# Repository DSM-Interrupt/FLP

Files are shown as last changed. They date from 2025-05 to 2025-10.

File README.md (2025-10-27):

# 구성

project FLP의 기기의 회로도, PCB, FW 코드 등이 담긴 파일입니다.
호스트 기기의 프레임 워크는 ESP-IDF를 이용하였고 Espressif ide를 이용하여서 CMAKE 형식의 프로젝트로 제작되었습니다.
터미널 기기의 프레임 워크는 STMCUBE를 이용하였습니다. 
host 기기의 같은경우 MCU는 ESP32-WROOM-32E를 이용하였으며 terminal기기의 경우 STM32F103C8T6을 사용하였습니다.

## 세부내용
### Hardware
- 433MHz 대역 통신을 위해 SX1278 모듈 기반의 안테나 매칭을 포함한 LoRa RF 공통 회로 설계
- MCP73831(Li-Po 충전) 및 AP2112K-3.3(LDO)을 사용하여 USB-C/배터리 입력을 받는 3.3V 전원 시스템 공통 회로 구성
- CP2104 USB-to-UART 브릿지 IC와 USB-C 커넥터를 사용한 PC 시리얼 통신 및 펌웨어 다운로드 공통 회로 구현
- L86-M33 GPS 모듈을 탑재하여 위치 정보 수집을 위한 공통 회로 및 안테나 인터페이스 설계
- Host(ESP32) 보드에 펌웨어의 효율적인 디버깅을 위한 JTAG 인터페이스 회로 추가 설계

### Firmware
- Host(ESP32) 펌웨어는 C 언어와 ESP-IDF(FreeRTOS)를 기반으로, Terminal(STM32F103) 펌웨어는 C 언어와 HAL 라이브러리를 기반으로 개발하여 LoRa 통신 시스템을 구축
- Terminal은 UART2로 GPS 모듈의 NMEA 센텐스를 파싱하며, 5초 주기 또는 '호출'/'위험' 버튼 입력 시 고유 ID, GPS 좌표, Target ID, 위험 상태를 "ID,Lat,Lon,TargetID,Danger" 형식의 문자열 패킷으로 LoRa 전송
- Host는 SPI를 통해 이 LoRa 패킷을 수신, split_lora_response 함수로 파싱하여 Target ID를 확인하고, TerminalDevice 구조체 배열로 관리되는 단말기 목록의 최신 GPS 좌표와 위험 상태를 갱신
- Host는 Wi-Fi(AP+STA 모드)로 인터넷에 연결하며, WSS 클라이언트를 통해 원격 서버로 모든 단말기 정보와 자체 GPS 수신 정보를 통합하여 주기적으로 JSON 전송
- Wi-Fi AP 모드에서 Captive Portal 기능을 포함한 웹 서버를 구동하여 사용자에게 Wi-Fi 연결 정보 및 AP 정보 설정 페이지를 제공하며, 이 설정값들과 등록된 단말기 ID 목록은 NVS에 영속 저장
- 특정 GPIO 버튼(CTRL + FIND_HOST) 조합을 통해 10초간 '단말기 등록 모드'로 진입하며, 이 동안 수신된 "REG,<ID>,<TARGET_ID>" 형식의 LoRa 등록 요청 패킷을 처리하여 새로운 단말기를 시스템에 추가하고 NVS에 저장

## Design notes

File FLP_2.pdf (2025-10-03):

# FLP

## Find Lost People

## 열악한 상황 속에도 사용할 수 있는 범용 위치 관리 솔루션

## 프로젝트 차별점

가. 단가: 전용 기기로 설계되어 대량 생산이 용이하며, 부품 배치 최적화, 부품 수 축소 및 소자 용량 조정을

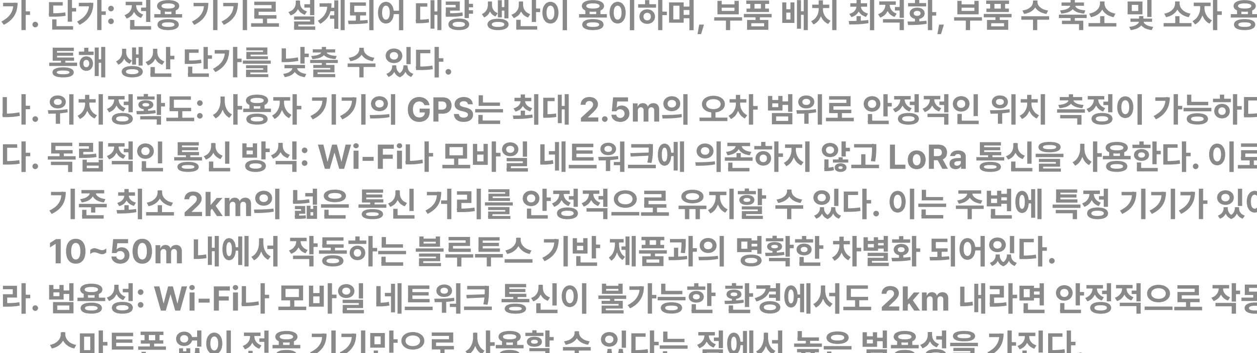
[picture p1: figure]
통해 생산 단가를 낮출 수 있다.

나. 위치정확도: 사용자 기기의 GPS는 최대 2.5m의 오차 범위로 안정적인 위치 측정이 가능하다.
다. 독립적인 통신 방식: Wi-Fi나 모바일 네트워크에 의존하지 않고 LoRa 통신을 사용한다. 이로써 도심 기준 최소 2km의 넓은 통신 거리를 안정적으로 유지할 수 있다. 이는 주변에 특정 기기가 있어야만 10~50m 내에서 작동하는 블루투스 기반 제품과의 명확한 차별화 되어있다.
라. 범용성: Wi-Fi나 모바일 네트워크 통신이 불가능한 환경에서도 2km 내라면 안정적으로 작동하며, 스마트폰 없이 전용 기기만으로 사용할 수 있다는 점에서 높은 범용성을 가진다.

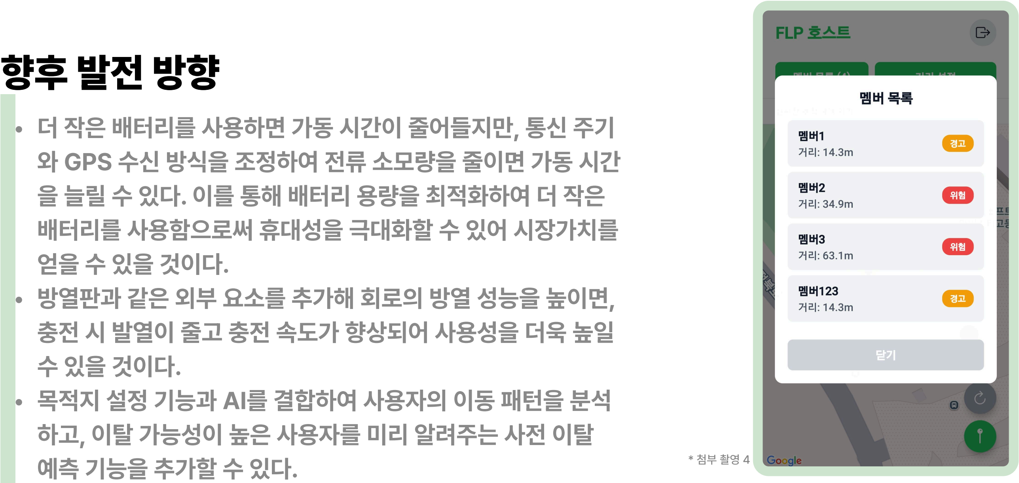
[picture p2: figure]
더 작은 배터리를 사용하면 가동 시간이 줄어들지만, 통신 주기 와 GPS 수신 방식을 조정하여 전류 소모량을 줄이면 가동 시간 을 늘릴 수 있다. 이를 통해 배터리 용량을 최적화하여 더 작은 배터리를 사용함으로써 휴대성을 극대화할 수 있어 시장가치를 얻을 수 있을 것이다. 방열판과 같은 외부 요소를 추가해 회로의 방열 성능을 높이면, 충전 시 발열이 줄고 충전 속도가 향상되어 사용성을 더욱 높일 수 있을 것이다. 목적지 설정 기능과 AI를 결합하여 사용자의 이동 패턴을 분석 하고, 이탈 가능성이 높은 사용자를 미리 알려주는 사전 이탈; 예측 기능을 추가할 수 있다.
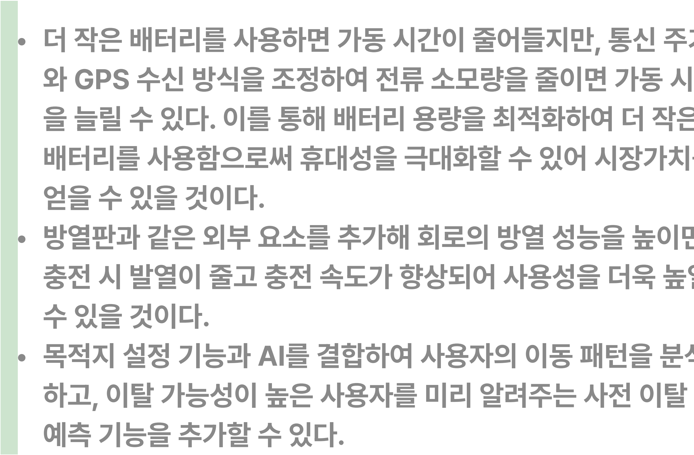
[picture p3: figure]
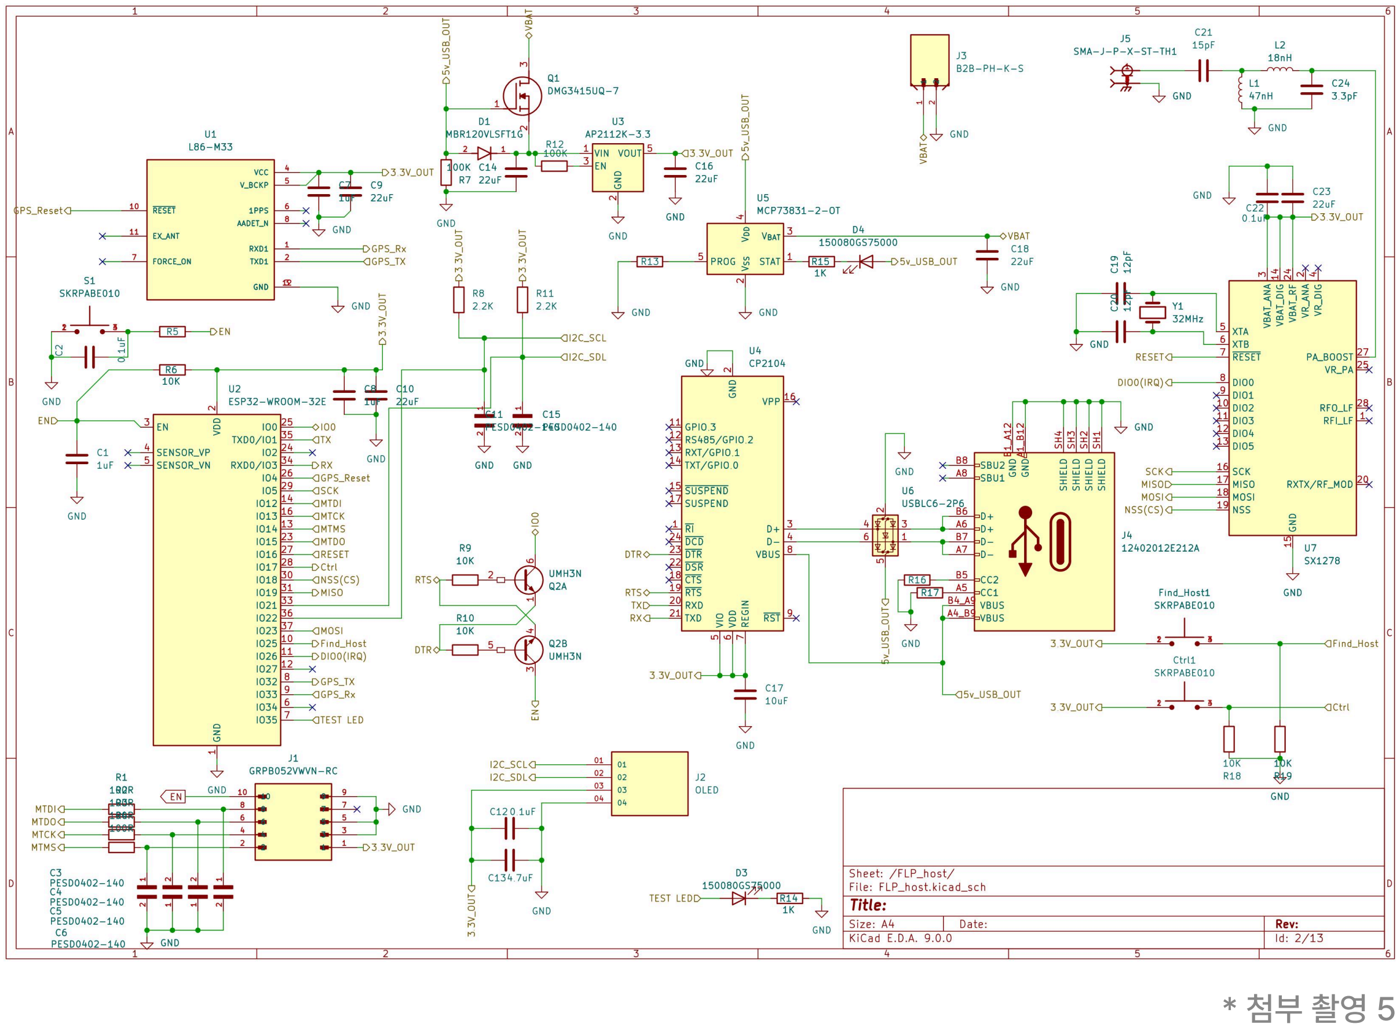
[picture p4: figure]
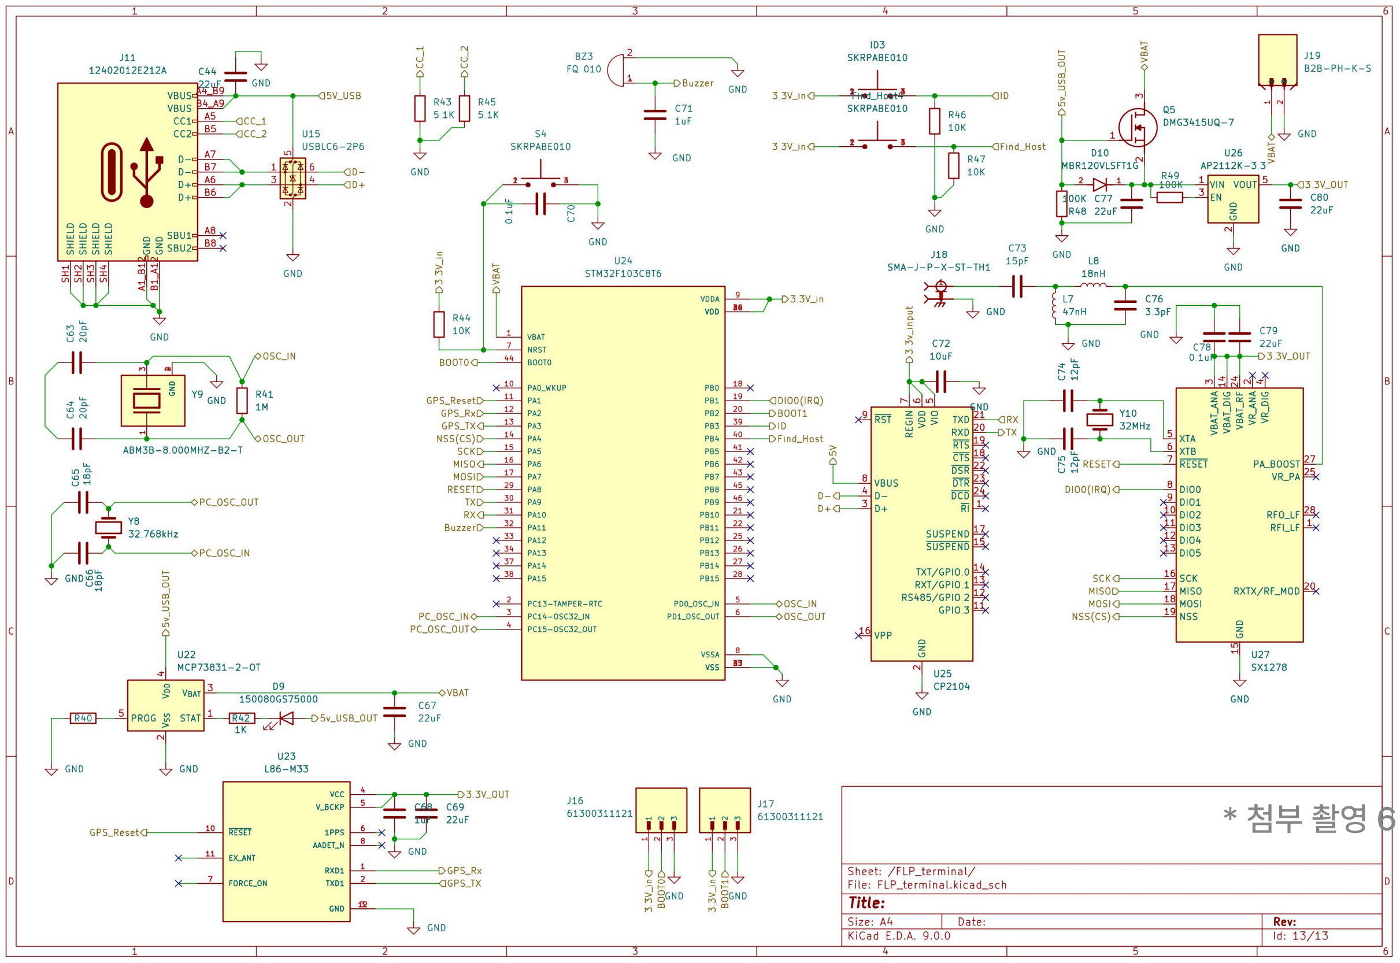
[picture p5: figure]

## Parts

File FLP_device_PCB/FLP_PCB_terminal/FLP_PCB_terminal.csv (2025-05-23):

Reference | Qty | Value | DNP | Exclude from BOM | Exclude from Board | Footprint | Datasheet
BT1 | 1 | Battery_Cell |  |  |  | Battery:BatteryHolder_MPD_BH-18650-PC2 | ~
BZ1 | 1 | Buzzer |  |  |  | Buzzer_Beeper:Buzzer_15x7.5RM7.6 | ~
C1,C2,C5,C10,C13,C16,C20,C29 | 8 | 22uF |  |  |  | Capacitor_SMD:C_0805_2012Metric | ~
C3,C11,C14,C15,C18,C23 | 6 | 4.7uF |  |  |  | Capacitor_SMD:C_0603_1608Metric | ~
C4,C8,C9,C19,C28 | 5 | 1uF |  |  |  | Capacitor_SMD:C_0603_1608Metric | ~
C6,C7 | 2 | 20pF |  |  |  | Capacitor_SMD:C_0402_1005Metric | ~
C12,C17,C24,C30,C31,C32 | 6 | 0.1uF |  |  |  | Capacitor_SMD:C_0603_1608Metric | ~
C21,C22 | 2 | PESD0402-140 |  |  |  | PESD0402-140:RESC1005X35N
C25,C26 | 2 | 12pF |  |  |  | Capacitor_SMD:C_0402_1005Metric | ~
C27 | 1 | 27pF |  |  |  | Capacitor_SMD:C_0603_1608Metric | ~
Charger1 | 1 | Charger |  |  |  | Connector_USB:USB_Micro-B_Amphenol_10103594-0001LF_Horizontal | ~
D1 | 1 | D_Schottky |  |  |  | Diode_SMD:DIOM5226X220N | ~
F1 | 1 | Polyfuse |  |  |  | Resistor_SMD:R_0603_1608Metric | ~
Find_Host1,ID1,S1,S2 | 4 | SKRPABE010 |  |  |  | Diode_SMD:SW_SKRPABE010
FL1 | 1 | BLM21PG221SN1D |  |  |  | BLM21PG221SN1D:BEADC2012X105N
J1 | 1 | SMA-J-P-X-ST-TH1 |  |  |  | SMA-J-P-X-ST-TH1:SAMTEC_SMA-J-P-X-ST-TH1
J2 | 1 | OLED |  |  |  | HTSW-104-20-TM-S:SAMTEC_HTSW-104-20-TM-S
L1 | 1 | 2.2uH |  |  |  | Inductor_SMD:L_1210_3225Metric | ~
L2 | 1 | WE-TPC_2811 |  |  |  | WE-TPC_2811:WE-TPC_2811
Q1 | 1 | Q_PMOS_DSG |  |  |  | SI2333DS-T1-E3:SOT95P237X112-3N | ~
R1,R2,R5,R6,R7,R14,R19,R20 | 8 | 10K |  |  |  | Resistor_SMD:R_0603_1608Metric | ~
R3 | 1 | 100R |  |  |  | Resistor_SMD:R_0402_1005Metric | ~
R4,R10 | 2 | 1K |  |  |  | Resistor_SMD:R_0603_1608Metric | ~
R8,R9 | 2 | 22R |  |  |  | Resistor_SMD:R_0402_1005Metric | ~
R11 | 1 | 1M |  |  |  | Resistor_SMD:R_0603_1608Metric | ~
R12 | 1 | 2M |  |  |  | Resistor_SMD:R_1210_3225Metric | ~
R13 | 1 | 180K |  |  |  | Resistor_SMD:R_1210_3225Metric | ~
R15,R18 | 2 | 2.2K |  |  |  | Resistor_SMD:R_0603_1608Metric | ~
R16,R17 | 2 | 5.1K |  |  |  | Resistor_SMD:R_0402_1005Metric | ~
U1 | 1 | AMS1117-3.3 |  |  |  | Package_TO_SOT_SMD:SOT-223-3_TabPin2 | http://www.advanced-monolithic.com/pdf/ds1117.pdf
U2 | 1 | STM32F103C8T6 |  |  |  | STM32F103C8T6:QFP50P900X900X160-48N
U3 | 1 | L86-M33 |  |  |  | L86-M33:XCVR_L86-M33
U4 | 1 | MCP73831-2-OT |  |  |  | Package_TO_SOT_SMD:SOT95P280X145-5N | http://ww1.microchip.com/downloads/en/DeviceDoc/20001984g.pdf
U5 | 1 | CP2104 |  |  |  | Package_DFN_QFN:QFN-24-1EP_4x4mm_P0.5mm_EP2.6x2.6mm | https://www.silabs.com/documents/public/data-sheets/cp2104.pdf
U6 | 1 | TPS61200DRC |  |  |  | Package_SON:Texas_S-PVSON-N10_ThermalVias | http://www.ti.com/lit/ds/symlink/tps61200.pdf
U7 | 1 | USBLC6-2P6 |  |  |  | Package_TO_SOT_SMD:SOT-666 | https://www.st.com/resource/en/datasheet/usblc6-2.pdf
U8 | 1 | SX1278 |  |  |  | Package_DFN_QFN:QFN-28-1EP_6x6mm_P0.65mm_EP4.8x4.8mm | https://semtech.my.salesforce.com/sfc/p/
UART1 | 1 | USB_C_Receptacle_USB2.0_16P |  |  |  | 12402012E212A:AMPHENOL_12402012E212A | https://www.usb.org/sites/default/files/documents/usb_type-c.zip
Y1 | 1 | ABM3B-8.000MHZ-B2-T |  |  |  | ABM3B-8.000MHZ-B2-T:XTAL_ABM3B-8.000MHZ-B2-T
Y2 | 1 | 32MHz |  |  |  | Crystal:Crystal_SMD_2012-2Pin_2.0x1.2mm | ~
Y3 | 1 | 32.768kHz |  |  |  | Crystal:Crystal_SMD_3215-2Pin_3.2x1.5mm | ~

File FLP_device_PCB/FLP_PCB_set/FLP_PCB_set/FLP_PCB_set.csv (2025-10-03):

Reference | Qty | Value | DNP | Exclude from BOM | Exclude from Board | Footprint | Datasheet
BZ1 | 1 | FQ 010 |  |  |  | Buzzer_Beeper:Buzzer_12x9.5RM7.6 | ~
C1,C7,C8,C28,C37 | 5 | 1uF |  |  |  | Capacitor_SMD:C_0603_1608Metric | ~
C2,C12,C22,C33,C36 | 5 | 0.1uF |  |  |  | Capacitor_SMD:C_0603_1608Metric | ~
C3,C4,C5,C6,C11,C15 | 6 | PESD0402-140 |  |  |  | PESD0402-140:RESC1005X35N
C9,C10,C14,C16,C18,C23,C25,C26,C27,C29,C34,C42 | 12 | 22uF |  |  |  | Capacitor_SMD:C_0805_2012Metric | ~
C13 | 1 | 4.7uF |  |  |  | Capacitor_SMD:C_0603_1608Metric | ~
C17 | 1 | 10uF |  |  |  | Capacitor_SMD:C_0805_2012Metric | ~
C19,C20,C30,C31 | 4 | 12pF |  |  |  | Capacitor_SMD:C_0402_1005Metric | ~
C21,C32 | 2 | 15pF |  |  |  | Capacitor_SMD:C_0402_1005Metric | ~
C24,C35 | 2 | 3.3pF |  |  |  | Capacitor_SMD:C_0402_1005Metric | ~
C38,C39 | 2 | 20pF |  |  |  | Capacitor_SMD:C_0402_1005Metric | ~
C40,C41 | 2 | 18pF |  |  |  | Capacitor_SMD:C_0603_1608Metric | ~
Ctrl1,Find_Host1,Find_Host2,ID1,S1,S2 | 6 | SKRPABE010 |  |  |  | Diode_SMD:SW_SKRPABE010
D1,D5 | 2 | MBR120VLSFT1G |  |  |  | MBR120VLSFT1G:DIOM3616X98N
D3,D4,D7 | 3 | 150080GS75000 |  |  |  | LED_SMD:LED_0805_2012Metric | ~
J1 | 1 | GRPB052VWVN-RC |  |  |  | Varistor:SULLINS_GRPB052VWVN-RC
J2 | 1 | OLED |  |  |  | HTSW-104-20-TM-S:SAMTEC_HTSW-104-20-TM-S
J3,J7 | 2 | B2B-PH-K-S |  |  |  | B2B_PH_K_S:JST_B2B-PH-K-S
J4,J6 | 2 | 12402012E212A |  |  |  | 12402012E212A:AMPHENOL_12402012E212A | https://www.usb.org/sites/default/files/documents/usb_type-c.zip
J5,J8 | 2 | SMA-J-P-X-ST-TH1 |  |  |  | SMA-J-P-X-ST-TH1:SAMTEC_SMA-J-P-X-ST-TH1
J9,J10 | 2 | 61300311121 |  |  |  | 61300311121:WURTH_61300311121
L1,L3 | 2 | 47nH |  |  |  | Inductor_SMD:L_0402_1005Metric | ~
L2 | 1 | 18nH |  |  |  | Capacitor_SMD:C_0402_1005Metric | ~
L4 | 1 | 18nH |  |  |  | Inductor_SMD:L_0402_1005Metric | ~
Q1,Q3 | 2 | DMG3415UQ-7 |  |  |  |  | https://www.diodes.com//assets/Datasheets/products_inactive_data/DMG3415UQ.pdf
Q2 | 1 | UMH3N |  |  |  | Package_TO_SOT_SMD:SOT-363_SC-70-6 | http://rohmfs.rohm.com/en/products/databook/datasheet/discrete/transistor/digital/emh3t2r-e.pdf
R1,R2,R3,R4 | 4 | 100R |  |  |  | Resistor_SMD:R_0603_1608Metric | ~
R5 | 1 | 22R |  |  |  | Resistor_SMD:R_0402_1005Metric | ~
R6,R9,R10,R18,R19,R26,R28,R29 | 8 | 10K |  |  |  | Resistor_SMD:R_0603_1608Metric | ~
R7,R12,R22,R23 | 4 | 100K |  |  |  | Resistor_SMD:R_0603_1608Metric | ~
R8,R11 | 2 | 2.2K |  |  |  | Resistor_SMD:R_0603_1608Metric | ~
R13,R24 | 2 | 2K |  |  |  | Resistor_SMD:R_0402_1005Metric | ~
R14,R15,R25 | 3 | 1K |  |  |  | Resistor_SMD:R_0603_1608Metric | ~
R16,R17 | 2 | 5.1K |  |  |  | Resistor_SMD:R_0402_1005Metric | ~
R20,R21 | 2 | 5.1K |  |  |  | Resistor_SMD:R_0603_1608Metric | ~
R27 | 1 | 1M |  |  |  | Resistor_SMD:R_0603_1608Metric | ~
U1,U12 | 2 | L86-M33 |  |  |  | L86-M33:XCVR_L86-M33
U2 | 1 | ESP32-WROOM-32E |  |  |  | RF_Module:ESP32-WROOM-32E | https://www.espressif.com/sites/default/files/documentation/esp32-wroom-32e_esp32-wroom-32ue_datasheet_en.pdf
U3,U10 | 2 | AP2112K-3.3 |  |  |  | Package_TO_SOT_SMD:SOT-23-5 | https://www.diodes.com/assets/Datasheets/AP2112.pdf
U4 | 1 | CP2104 |  |  |  | Package_DFN_QFN:QFN-24-1EP_4x4mm_P0.5mm_EP2.6x2.6mm | https://www.silabs.com/documents/public/data-sheets/cp2104.pdf
U5,U11 | 2 | MCP73831-2-OT |  |  |  | Package_TO_SOT_SMD:SOT-23-5 | http://ww1.microchip.com/downloads/en/DeviceDoc/20001984g.pdf
U6,U8 | 2 | USBLC6-2P6 |  |  |  | Package_TO_SOT_SMD:SOT-666 | https://www.st.com/resource/en/datasheet/usblc6-2.pdf
U7,U13 | 2 | SX1278 |  |  |  | Package_DFN_QFN:QFN-28-1EP_6x6mm_P0.65mm_EP4.8x4.8mm | https://semtech.my.salesforce.com/sfc/p/
U9 | 1 | STM32F103C8T6 |  |  |  | STM32F103C8T6:QFP50P900X900X160-48N
U14 | 1 | CH340N |  |  |  | Package_SO:SOP-8_3.9x4.9mm_P1.27mm | https://aitendo3.sakura.ne.jp/aitendo_data/product_img/ic/inteface/CH340N/ch340n.pdf
Y1,Y2 | 2 | 32MHz |  |  |  | Crystal:Crystal_SMD_2016-4Pin_2.0x1.6mm | ~
Y3 | 1 | ABM3B-8.000MHZ-B2-T |  |  |  | ABM3B-8.000MHZ-B2-T:XTAL_ABM3B-8.000MHZ-B2-T
Y4 | 1 | 32.768kHz |  |  |  | Crystal:Crystal_SMD_3215-2Pin_3.2x1.5mm | ~

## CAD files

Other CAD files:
case.blend
untitled.blend

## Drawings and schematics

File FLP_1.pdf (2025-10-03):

# FLP

## Find Lost People

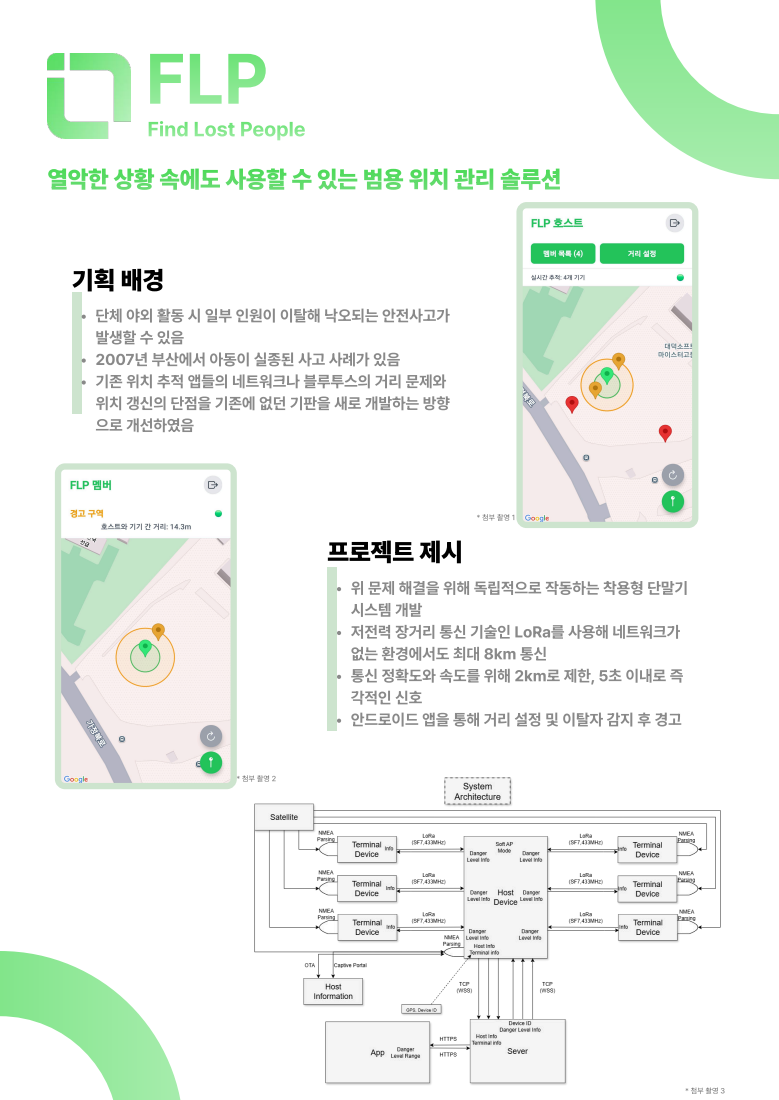
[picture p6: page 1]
프로젝트 제시

열악한 상황 속에도 사용할 수 있는 범용 위치 관리 솔루션

단체 야외 활동 시 일부 인원이 이탈해 낙오되는 안전사고가
발생할 수 있음
2007년 부산에서 아동이 실종된 사고 사례가 있음
기존 위치 추적 앱들의 네트워크나 블루투스의 거리 문제와
위치 갱신의 단점을 기존에 없던 기판을 새로 개발하는 방향
으로 개선하였음

위 문제 해결을 위해 독립적으로 작동하는 착용형 단말기
시스템 개발
저전력 장거리 통신 기술인 LoRa를 사용해 네트워크가
없는 환경에서도 최대 8km 통신
통신 정확도와 속도를 위해 2km로 제한, 5초 이내로 즉
각적인 신호
안드로이드 앱을 통해 거리 설정 및 이탈자 감지 후 경고

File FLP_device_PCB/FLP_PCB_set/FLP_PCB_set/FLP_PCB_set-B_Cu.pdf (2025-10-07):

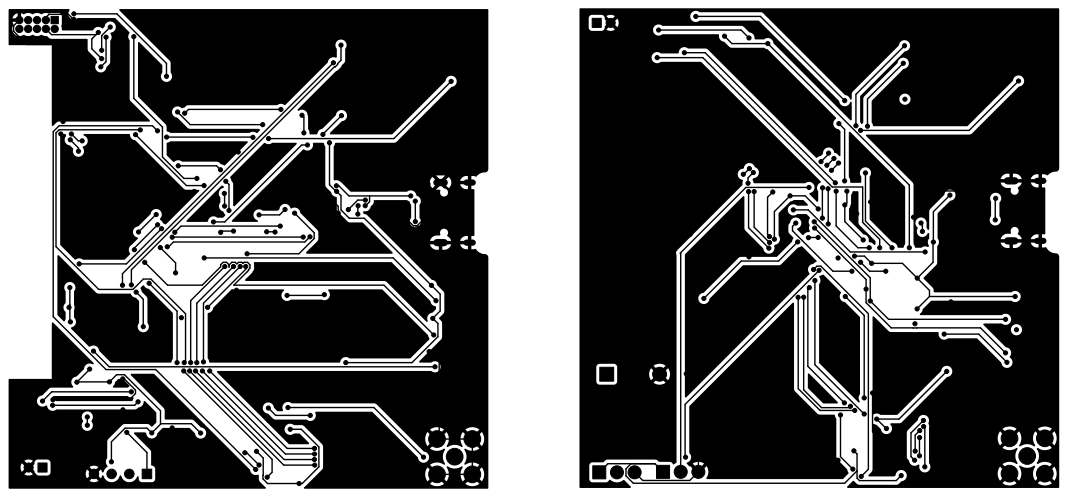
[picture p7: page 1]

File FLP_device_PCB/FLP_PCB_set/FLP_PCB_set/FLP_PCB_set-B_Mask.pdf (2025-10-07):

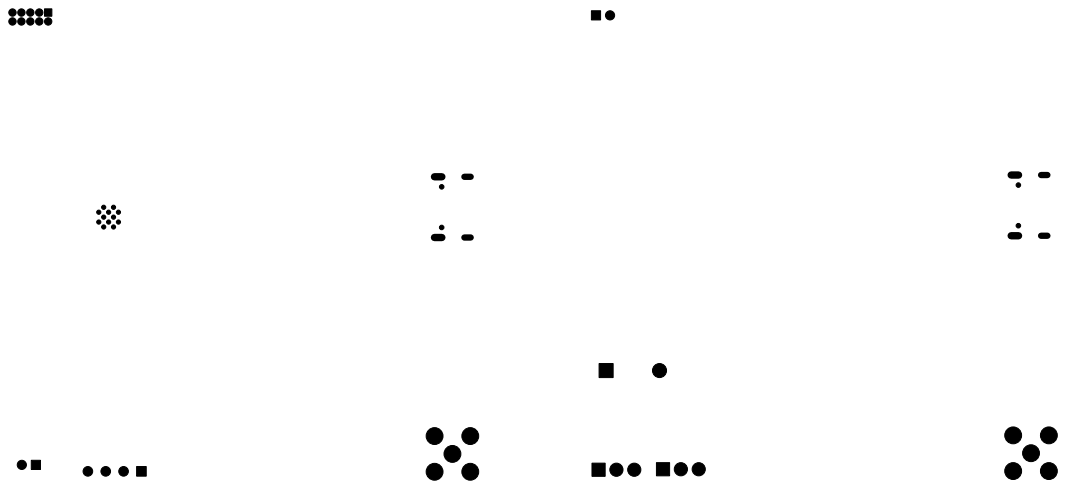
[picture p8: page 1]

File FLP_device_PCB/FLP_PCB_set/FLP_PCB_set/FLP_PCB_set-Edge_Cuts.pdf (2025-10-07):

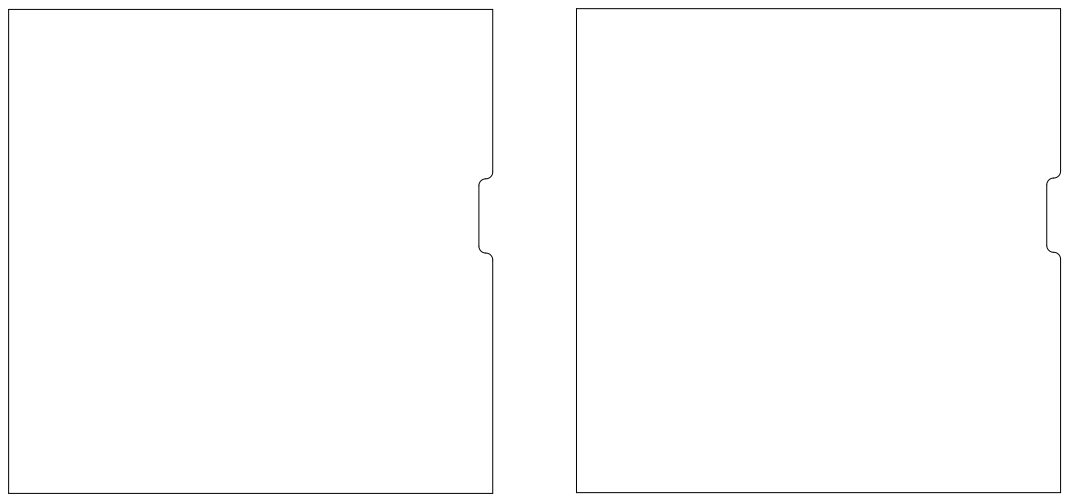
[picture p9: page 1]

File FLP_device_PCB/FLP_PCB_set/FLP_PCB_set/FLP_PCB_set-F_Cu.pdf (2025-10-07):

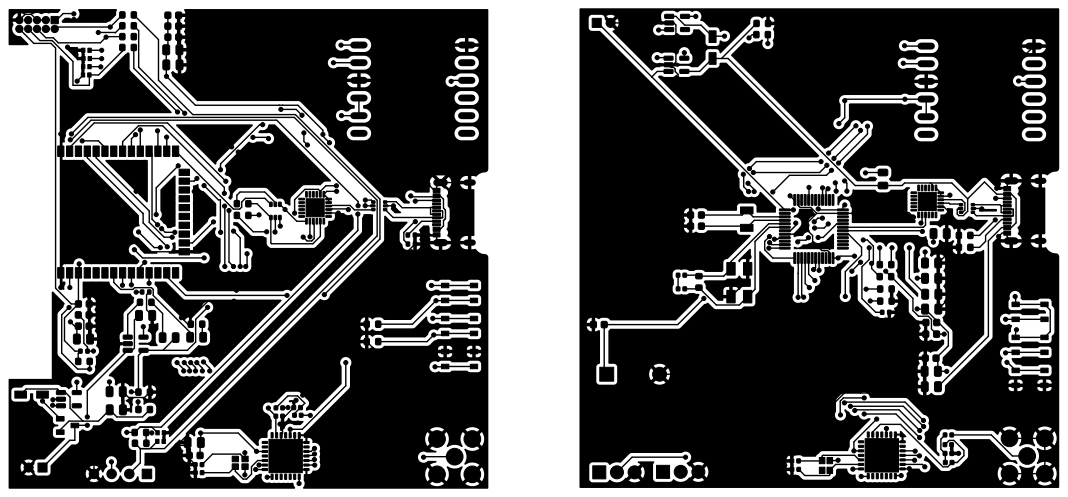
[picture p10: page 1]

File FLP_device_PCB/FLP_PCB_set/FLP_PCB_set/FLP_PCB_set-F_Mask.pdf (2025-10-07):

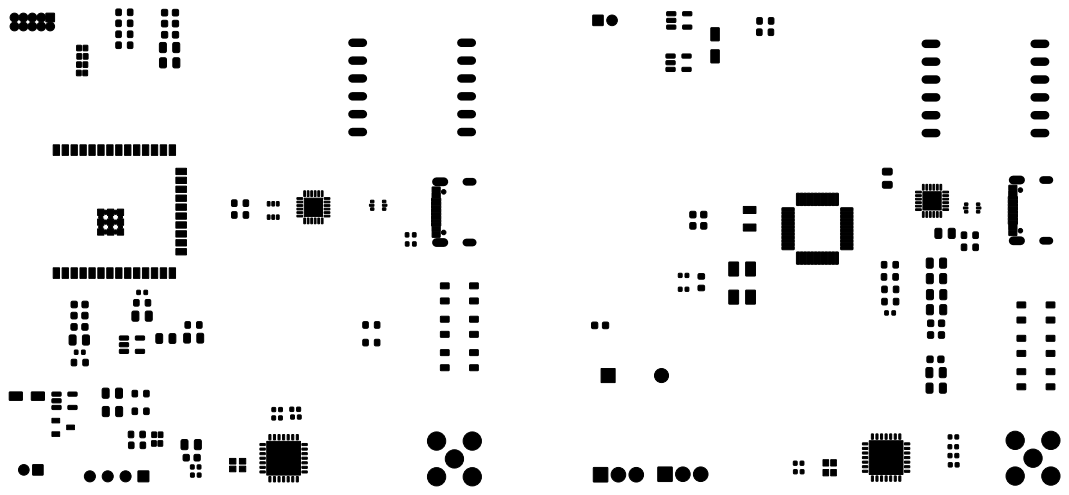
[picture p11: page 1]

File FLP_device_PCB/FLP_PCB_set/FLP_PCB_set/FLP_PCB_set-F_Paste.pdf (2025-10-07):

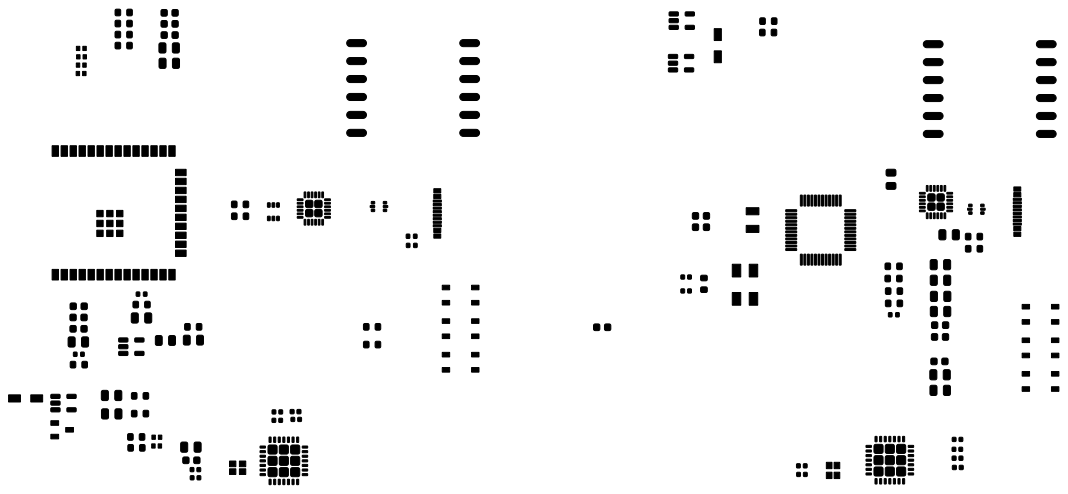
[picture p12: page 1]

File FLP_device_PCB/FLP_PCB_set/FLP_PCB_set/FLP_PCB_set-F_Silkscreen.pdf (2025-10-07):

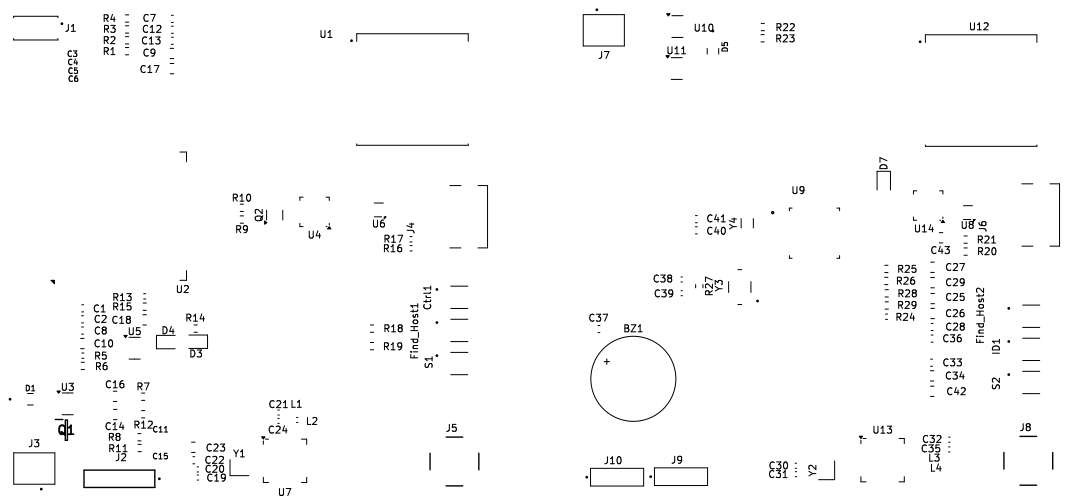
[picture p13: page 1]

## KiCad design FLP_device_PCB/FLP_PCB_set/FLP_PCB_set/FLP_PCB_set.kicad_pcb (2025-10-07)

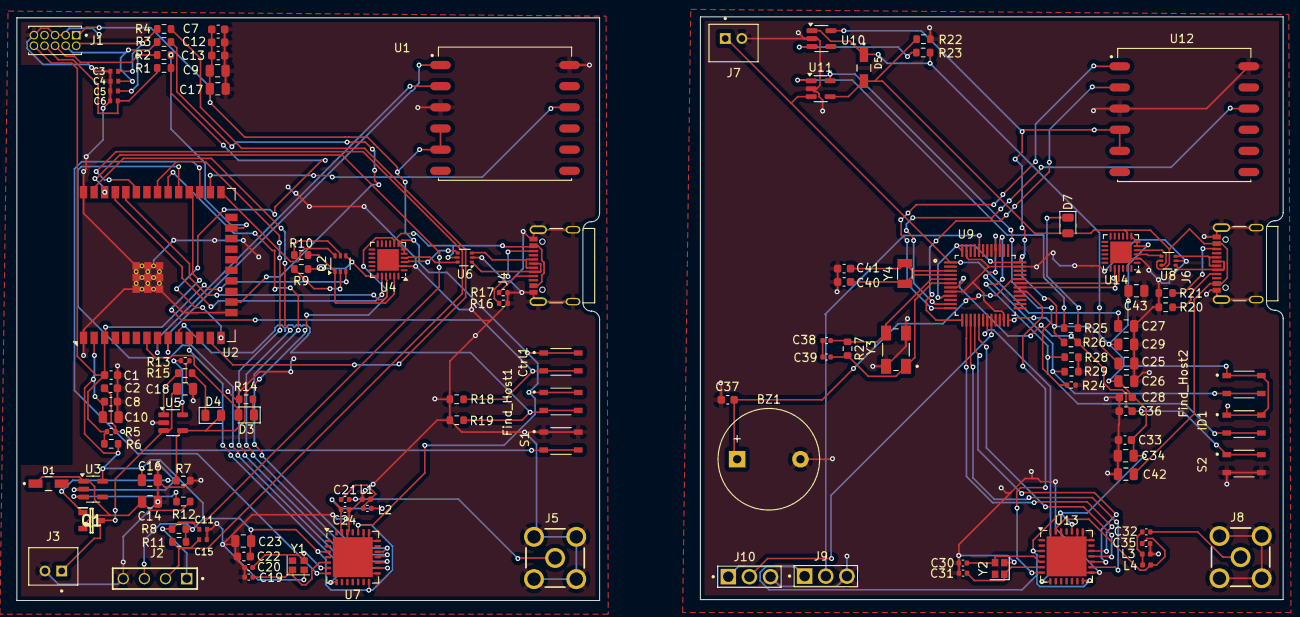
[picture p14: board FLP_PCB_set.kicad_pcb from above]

Board: 2 copper layers, 152.1 x 70.1 mm, 118 parts (0 on the bottom side), 93 nets.

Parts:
BZ1: FQ 010; Buzzer_12x9.5RM7.6
C1, C7, C8, C28, C37: 1uF; C_0603_1608Metric
C2, C12, C22, C33, C36: 0.1uF; C_0603_1608Metric
C3, C4, C5, C6, C11, C15: PESD0402-140; RESC1005X35N
C9, C10, C14, C16, C18, C23, C25, C26, C27, C29, C34, C42: 22uF; C_0805_2012Metric
C13: 4.7uF; C_0603_1608Metric
C17, C43: 10uF; C_0805_2012Metric
C19, C20, C30, C31: 12pF; C_0402_1005Metric
C21, C32: 15pF; C_0402_1005Metric
C24, C35: 3.3pF; C_0402_1005Metric
C38, C39: 20pF; C_0402_1005Metric
C40, C41: 18pF; C_0603_1608Metric
Ctrl1: SKRPABE010; SW_SKRPABE010
D1, D5: MBR120VLSFT1G; DIOM3616X98N
D3, D4, D7: 150080GS75000; LED_0805_2012Metric
Find_Host1, Find_Host2: SKRPABE010; SW_SKRPABE010
ID1: SKRPABE010; SW_SKRPABE010
J1: GRPB052VWVN-RC; SULLINS_GRPB052VWVN-RC
J2: OLED; SAMTEC_HTSW-104-20-TM-S
J3, J7: B2B-PH-K-S; JST_B2B-PH-K-S
J4, J6: 12402012E212A; AMPHENOL_12402012E212A
J5, J8: SMA-J-P-X-ST-TH1; SAMTEC_SMA-J-P-X-ST-TH1
J9, J10: 61300311121; WURTH_61300311121
L1, L3: 47nH; L_0402_1005Metric
L2: 18nH; C_0402_1005Metric
L4: 18nH; L_0402_1005Metric
Q1: DMG3415UQ-7; SOT96P240X110-3N
Q2: UMH3N; SOT-363_SC-70-6
R1, R2, R3, R4: 100R; R_0603_1608Metric
R5: 22R; R_0402_1005Metric
R6, R9, R10, R18, R19, R26, R28, R29: 10K; R_0603_1608Metric
R7, R12, R22, R23: 100K; R_0603_1608Metric
R8, R11: 2.2K; R_0603_1608Metric
R13, R24: 2K; R_0402_1005Metric
R14, R15, R25: 1K; R_0603_1608Metric
R16, R17: 5.1K; R_0402_1005Metric
R20, R21: 5.1K; R_0603_1608Metric
R27: 1M; R_0603_1608Metric
S1, S2: SKRPABE010; SW_SKRPABE010
U1, U12: L86-M33; XCVR_L86-M33
U2: ESP32-WROOM-32E
U3, U10: AP2112K-3.3; SOT-23-5
U4, U14: CP2104; QFN-24-1EP_4x4mm_P0.5mm_EP2.6x2.6mm
U5, U11: MCP73831-2-OT; SOT-23-5
U6, U8: USBLC6-2P6; SOT-666
U7, U13: SX1278; QFN-28-1EP_6x6mm_P0.65mm_EP4.8x4.8mm
U9: STM32F103C8T6; QFP50P900X900X160-48N
Y1, Y2: 32MHz; Crystal_SMD_2016-4Pin_2.0x1.6mm
Y3: ABM3B-8.000MHZ-B2-T; XTAL_ABM3B-8.000MHZ-B2-T
Y4: 32.768kHz; Crystal_SMD_3215-2Pin_3.2x1.5mm

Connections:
/FLP_host/3.3V_OUT: C7.1, C8.1, C9.1, C10.1, C12.1, C13.1, C16.1, C17.1, C22.1, C23.2, Ctrl1.1, Ctrl1.2, Find_Host1.1, Find_Host1.2, J1.1, J2.03, R6.2, R8.2, R11.2, U1.4 (VCC), U1.5 (V_BCKP), U2.2 (VDD), U3.5 (VOUT), U4.5 (VIO), U4.6 (VDD), U4.7 (REGIN), U7.3 (VBAT_ANA), U7.14 (VBAT_DIG), U7.24 (VBAT_RF)
/FLP_host/5v_USB_OUT: D1.2, D4.2 (A), J4.A4_B9 (VBUS), J4.B4_A9 (VBUS), Q1.1 (G), R7.1, U4.8 (VBUS), U5.4 (V_{DD}), U6.5 (VBUS)
/FLP_host/Ctrl: Ctrl1.3, Ctrl1.4, R18.1, U2.28 (IO17)
/FLP_host/DIO0(IRQ): U2.11 (IO26), U7.8 (DIO0)
/FLP_host/DTR: Q2.1 (E1), R10.1, U4.23 (~DTR)
/FLP_host/Find_Host: Find_Host1.3, Find_Host1.4, R19.1, U2.10 (IO25)
/FLP_host/GPS_Reset: U1.10 (~RESET), U2.26 (IO4)
/FLP_host/GPS_Rx: U1.1 (RXD1), U2.9 (IO33)
/FLP_host/GPS_TX: U1.2 (TXD1), U2.8 (IO32)
/FLP_host/I2C_SCL: C11.1, J2.01, R8.1, U2.36 (IO22)
/FLP_host/I2C_SDL: C15.1, J2.02, R11.1, U2.33 (IO21)
/FLP_host/IO0: Q2.6 (C1), U2.25 (IO0)
/FLP_host/MISO: U2.31 (IO19), U7.17 (MISO)
/FLP_host/MOSI: U2.37 (IO23), U7.18 (MOSI)
/FLP_host/MTCK: R3.1, U2.16 (IO13)
/FLP_host/MTDI: R1.1, U2.14 (IO12)
/FLP_host/MTDO: R2.1, U2.23 (IO15)
/FLP_host/MTMS: R4.1, U2.13 (IO14)
/FLP_host/NSS(CS): U2.30 (IO18), U7.19 (NSS)
/FLP_host/RESET: U2.27 (IO16), U7.7 (~RESET)
/FLP_host/RTS: Q2.4 (E2), R9.1, U4.19 (~RTS)
/FLP_host/RX: U2.34 (RXD0/IO3), U4.21 (TXD)
/FLP_host/SCK: U2.29 (IO5), U7.16 (SCK)
/FLP_host/TEST LED: D3.2 (A), U2.7 (IO35)
/FLP_host/TX: U2.35 (TXD0/IO1), U4.20 (RXD)
/FLP_host/VBAT: C18.1, J3.1, Q1.3 (D), U5.3 (V_{BAT})
/FLP_terminal/BOOT_Mode/3.3V_in: C26.1, C28.1, C29.1, C33.1, C34.2, C43.1, Find_Host2.1, Find_Host2.2, ID1.1, ID1.2, J9.1, J10.1, R26.1, U9.9 (VDDA), U9.24 (VDD), U9.36 (VDD), U9.48 (VDD), U10.5 (VOUT), U12.4 (VCC), U12.5 (V_BCKP), U13.3 (VBAT_ANA), U13.14 (VBAT_DIG), U13.24 (VBAT_RF), U14.5 (VIO), U14.6 (VDD), U14.7 (REGIN)
/FLP_terminal/BOOT_Mode/BOOT0: J9.2, U9.44 (BOOT0)
/FLP_terminal/BOOT_Mode/BOOT1: J10.2, U9.20 (PB2)
/FLP_terminal/Bat/5v_USB_OUT: C42.2, D5.2, D7.2 (A), J6.A4_B9 (VBUS), J6.B4_A9 (VBUS), R22.1, U8.5 (VBUS), U11.4 (V_{DD}), U14.8 (VBUS)
/FLP_terminal/Bat/VBAT: C27.1, J7.1, U9.1 (VBAT), U11.3 (V_{BAT})
/FLP_terminal/GPS/GPS_Reset: U9.11 (PA1), U12.10 (~RESET)
/FLP_terminal/GPS/GPS_Rx: U9.12 (PA2), U12.1 (RXD1)
/FLP_terminal/GPS/GPS_TX: U9.13 (PA3), U12.2 (TXD1)
/FLP_terminal/LoRa/DIO0(IRQ): U9.19 (PB1), U13.8 (DIO0)
/FLP_terminal/LoRa/MISO: U9.16 (PA6), U13.17 (MISO)
/FLP_terminal/LoRa/MOSI: U9.17 (PA7), U13.18 (MOSI)
/FLP_terminal/LoRa/NSS(CS): U9.14 (PA4), U13.19 (NSS)
/FLP_terminal/LoRa/RESET: U9.29 (PA8), U13.7 (~RESET)
/FLP_terminal/LoRa/SCK: U9.15 (PA5), U13.16 (SCK)
/FLP_terminal/STM32/Buzzer: BZ1.1 (+), C37.1, U9.32 (PA11)
/FLP_terminal/STM32/Find_Host: Find_Host2.3, Find_Host2.4, R29.1, U9.40 (PB4)
/FLP_terminal/STM32/ID: ID1.3, ID1.4, R28.1, U9.39 (PB3)
/FLP_terminal/STM32/OSC_IN: C38.2, R27.1, U9.5 (PD0_OSC_IN), Y3.3
/FLP_terminal/STM32/OSC_OUT: C39.2, R27.2, U9.6 (PD1_OSC_OUT), Y3.1
/FLP_terminal/STM32/PC_OSC_IN: C41.1, U9.3 (PC14-OSC32_IN), Y4.1
/FLP_terminal/STM32/PC_OSC_OUT: C40.1, U9.4 (PC15-OSC32_OUT), Y4.2
/FLP_terminal/STM32/RX: U9.31 (PA10), U14.21 (TXD)
/FLP_terminal/STM32/TX: U9.30 (PA9), U14.20 (RXD)
/FLP_terminal/UART_USB/CC_1: J6.A5 (CC1), R20.1
/FLP_terminal/UART_USB/CC_2: J6.B5 (CC2), R21.1
/FLP_terminal/UART_USB/D+: U8.4 (I/O2), U14.3 (D+)
/FLP_terminal/UART_USB/D-: U8.6 (I/O1), U14.4 (D-)
EN: C1.1, J1.10, Q2.3 (C2), R5.2, R6.1, U2.3 (EN)
GND: BZ1.2 (-), C1.2, C2.1, C3.2, C4.1, C5.1, C6.2, C7.2, C8.2, C9.2, C10.2, C11.2, C12.2, C13.2, C14.2, C15.2, C16.2, C17.2, C18.2, C19.1, C20.1, C22.2, C23.1, C24.2, C25.2, C26.2, C27.2, C28.2, C29.2, C30.1, C31.1, C33.2, C34.1, C35.2, C36.1, C37.2, C40.2, C41.2, C42.1, C43.2, J1.3, J1.5, J1.9, J2.04, J3.2, J4.A1_B12 (GND), J4.B1_A12 (GND), J4.SH1 (SHIELD), J4.SH2 (SHIELD), J4.SH3 (SHIELD), J4.SH4 (SHIELD), J5.2, J5.3, J5.4, J5.5, J6.A1_B12 (GND), J6.B1_A12 (GND), J6.SH1 (SHIELD), J6.SH2 (SHIELD), J6.SH3 (SHIELD), J6.SH4 (SHIELD), J7.2, J8.2, J8.3, J8.4, J8.5, J9.3, J10.3, L1.1, L3.1, R7.2, R13.1, R14.2, R16.1, R17.1, R18.2, R19.2, R20.2, R21.2, R22.2, R24.1, R28.2, R29.2, S1.1, S1.2, S2.3, S2.4, U1.3 (GND), U1.12 (GND), U2.1 (GND), U2.15 (GND), U2.38 (GND), U2.39 (GND), U3.2 (GND), U4.2 (GND), U4.25 (GND), U5.2 (V_{SS}), U6.2 (GND), U7.15 (GND), U7.21 (GND), U7.22 (GND), U7.23 (GND), U7.26 (GND), U7.29 (GND), U8.2 (GND), U9.8 (VSSA), U9.23 (VSS), U9.35 (VSS), U9.47 (VSS), U10.2 (GND), U11.2 (V_{SS}), U12.3 (GND), U12.12 (GND), U13.15 (GND), U13.21 (GND), U13.22 (GND), U13.23 (GND), U13.26 (GND), U13.29 (GND), U14.2 (GND), U14.25 (GND), Y3.2 (GND), Y3.4 (GND)
unnamed: C2.2, R5.1, S1.3, S1.4
unnamed: C3.1, J1.2, R4.2
unnamed: C4.2, J1.4, R3.2
unnamed: C5.2, J1.6, R2.2
unnamed: C6.1, J1.8, R1.2
unnamed: C21.1, L1.2, L2.1
unnamed: C21.2, J5.1
unnamed: C32.1, L3.2, L4.1
unnamed: C32.2, J8.1
unnamed: C38.1, C39.1
unnamed: D3.1 (K), R14.1
unnamed: D4.1 (K), R15.2
unnamed: D7.1 (K), R25.2
unnamed: J4.A5 (CC1), R17.2
unnamed: J4.B5 (CC2), R16.2
unnamed: J4.A6 (D+), J4.B6 (D+), U6.3 (I/O2)
unnamed: J4.A7 (D-), J4.B7 (D-), U6.1 (I/O1)
unnamed: J6.A6 (D+), J6.B6 (D+), U8.3 (I/O2)
unnamed: J6.A7 (D-), J6.B7 (D-), U8.1 (I/O1)
unnamed: C14.1, D1.1, Q1.2 (S), R12.2, U3.1 (VIN)
unnamed: Q2.2 (B1), R9.2
unnamed: Q2.5 (B2), R10.2
unnamed: C25.1, D5.1, R23.2, U10.1 (VIN)
unnamed: R12.1, U3.3 (EN)
unnamed: U4.3 (D+), U6.4 (I/O2)
unnamed: U4.4 (D-), U6.6 (I/O1)
unnamed: R13.2, U5.5 (PROG)
unnamed: R15.1, U5.1 (STAT)
unnamed: C24.1, L2.2, U7.27 (PA_BOOST)
unnamed: C19.2, U7.5 (XTA), Y1.2
unnamed: C20.2, U7.6 (XTB), Y1.1
unnamed: C36.2, R26.2, S2.1, S2.2, U9.7 (NRST)
unnamed: R23.1, U10.3 (EN)
unnamed: R24.2, U11.5 (PROG)
unnamed: R25.1, U11.1 (STAT)
unnamed: C35.1, L4.2, U13.27 (PA_BOOST)
unnamed: C30.2, U13.5 (XTA), Y2.2
unnamed: C31.2, U13.6 (XTB), Y2.1

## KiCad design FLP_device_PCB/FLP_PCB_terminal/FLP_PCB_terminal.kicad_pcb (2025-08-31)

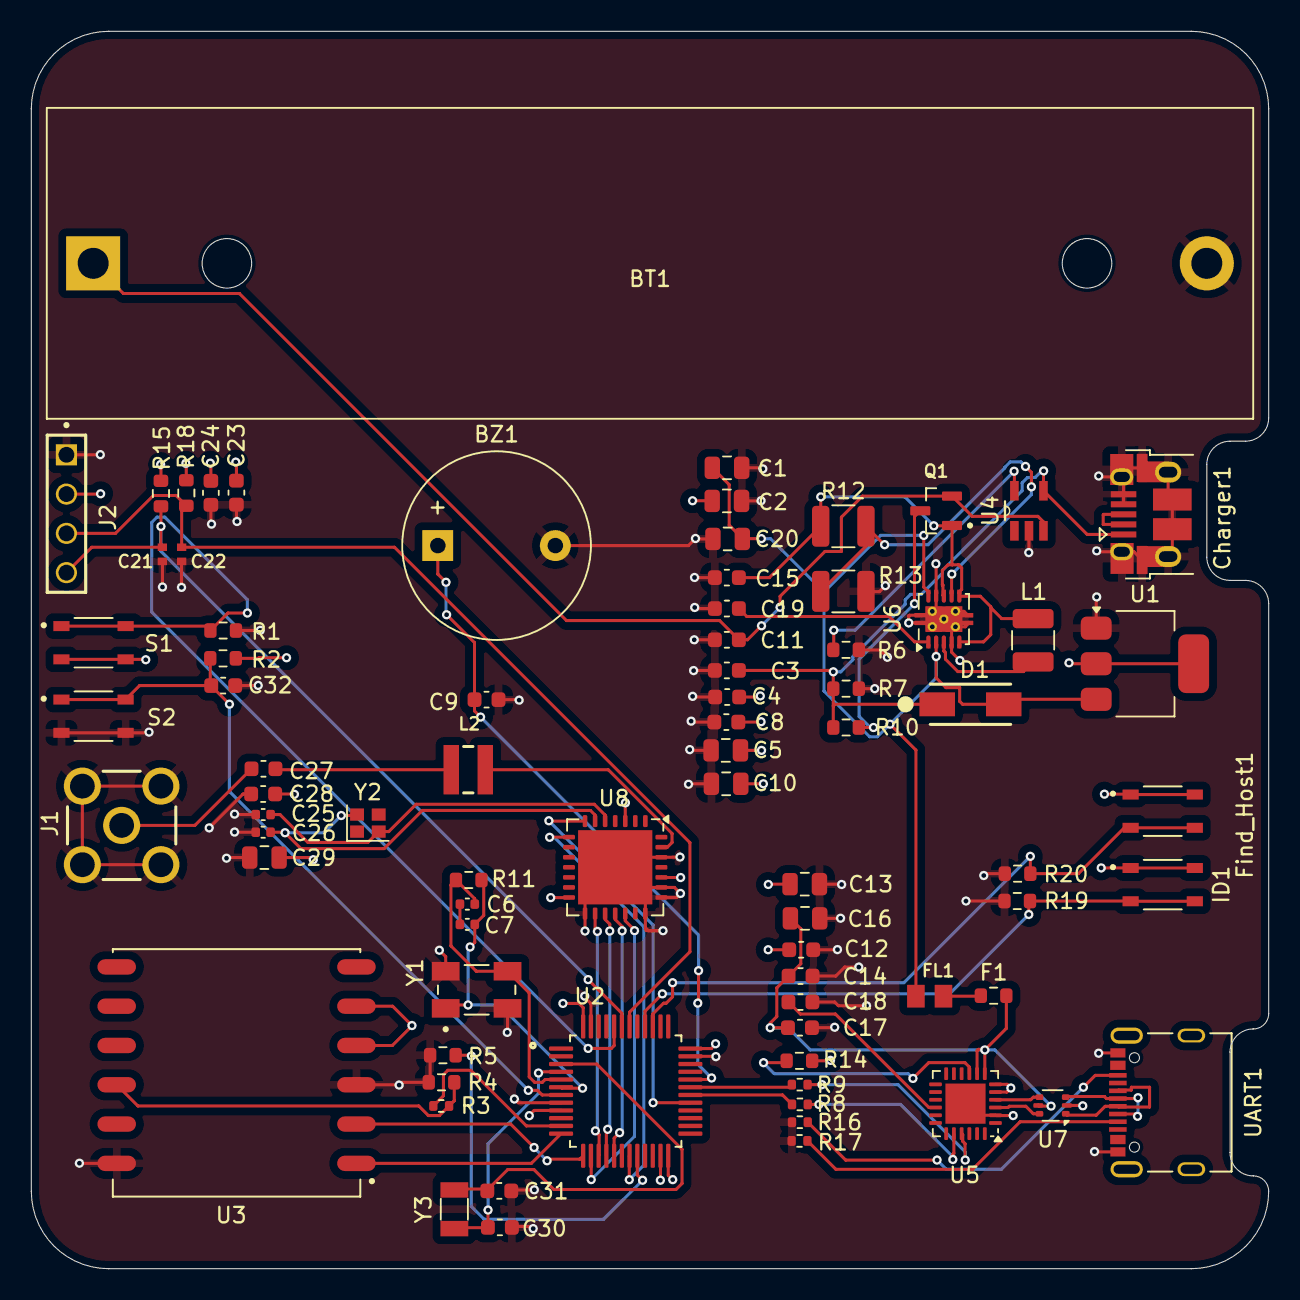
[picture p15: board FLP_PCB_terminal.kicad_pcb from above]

Board: 4 copper layers, 80.0 x 80.0 mm, 79 parts (0 on the bottom side), 54 nets.

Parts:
BT1: Battery_Cell; BatteryHolder_MPD_BH-18650-PC2
BZ1: Buzzer; Buzzer_12x9.5RM7.6
C1, C2, C5, C10, C13, C16, C20, C29: 22uF; C_0805_2012Metric
C3, C11, C14, C15, C18, C23: 4.7uF; C_0603_1608Metric
C4, C8, C9, C19, C28: 1uF; C_0603_1608Metric
C6, C7: 20pF; C_0402_1005Metric
C12, C17, C24, C30, C31, C32: 0.1uF; C_0603_1608Metric
C21, C22: PESD0402-140; RESC1005X35N
C25, C26: 12pF; C_0402_1005Metric
C27: 2.2pF; C_0603_1608Metric
Charger1: Charger; USB_Micro-B_Amphenol_10103594-0001LF_Horizontal
D1: D_Schottky; DIOM5226X220N
F1: Polyfuse; R_0603_1608Metric
FL1: BLM21PG221SN1D; BEADC2012X105N
Find_Host1: SKRPABE010; SW_SKRPABE010
ID1: SKRPABE010; SW_SKRPABE010
J1: SMA-J-P-X-ST-TH1; SAMTEC_SMA-J-P-X-ST-TH1
J2: OLED; SAMTEC_HTSW-104-20-TM-S
L1: 2.2uH; L_1210_3225Metric
L2: WE-TPC_2811
Q1: Q_PMOS_DSG; SOT95P237X112-3N
R1, R2, R5, R6, R7, R14, R19, R20: 10K; R_0603_1608Metric
R3: 100R; R_0402_1005Metric
R4, R10: 1K; R_0603_1608Metric
R8, R9: 22R; R_0402_1005Metric
R11: 1M; R_0603_1608Metric
R12: 2M; R_1210_3225Metric
R13: 180K; R_1210_3225Metric
R15, R18: 2.2K; R_0603_1608Metric
R16, R17: 5.1K; R_0402_1005Metric
S1, S2: SKRPABE010; SW_SKRPABE010
U1: AMS1117-3.3; SOT-223-3_TabPin2
U2: STM32F103C8T6; QFP50P900X900X160-48N
U3: L86-M33; XCVR_L86-M33
U4: MCP73831-2-OT; SOT95P280X145-5N
U5: CP2104; QFN-24-1EP_4x4mm_P0.5mm_EP2.6x2.6mm
U6: TPS61200DRC; Texas_S-PVSON-N10_ThermalVias
U7: USBLC6-2P6; SOT-666
U8: SX1278; QFN-28-1EP_6x6mm_P0.65mm_EP4.8x4.8mm
UART1: USB_C_Receptacle_USB2.0_16P; AMPHENOL_12402012E212A
Y1: ABM3B-8.000MHZ-B2-T; XTAL_ABM3B-8.000MHZ-B2-T
Y2: 32MHz; Crystal_SMD_2016-4Pin_2.0x1.6mm
Y3: 32.768kHz; Crystal_SMD_3215-2Pin_3.2x1.5mm

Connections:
3.3V OUT: C2.1, C4.2, C5.2, C8.2, C10.2, C12.1, C13.2, C23.1, C24.1, C28.2, C29.2, Find_Host1.1, Find_Host1.2, ID1.1, ID1.2, J2.02, R2.1, R14.2, R15.2, R18.2, S1.3, S1.4, U1.2 (VO), U2.9 (VDDA), U2.24 (VDD), U2.36 (VDD), U2.48 (VDD), U3.4 (VCC), U3.5 (V_BCKP), U5.5 (VIO), U5.6 (VDD), U8.3 (VBAT_ANA), U8.14 (VBAT_DIG), U8.24 (VBAT_RF)
5v OUT: C1.1, C20.1, FL1.2, U1.3 (VI), U6.2 (VOUT), U6.10 (FB)
BOOT0: R1.2, S1.1, S1.2, U2.44 (BOOT0)
Buzzer: BZ1.1 (+), C9.1, U2.32 (PA11)
DIO0(IRQ): U2.19 (PB1), U8.8 (DIO0)
Find_Host: Find_Host1.3, Find_Host1.4, R20.2, U2.39 (PB3)
GND: BT1.2 (-), BZ1.2 (-), C1.2, C2.2, C3.2, C4.1, C5.1, C8.1, C9.2, C10.1, C11.2, C12.2, C13.1, C14.2, C15.2, C16.2, C17.1, C18.2, C19.2, C20.2, C21.2, C22.2, C23.2, C24.2, C25.1, C26.1, C28.1, C29.1, C30.2, C31.2, C32.1, Charger1.4 (ID), Charger1.5 (GND), Charger1.6 (Shield), J1.2, J1.3, J1.4, J1.5, J2.01, R1.1, R4.1, R5.1, R6.2, R7.2, R13.2, R16.1, R17.1, R19.1, R20.1, S2.3, S2.4, U1.1 (GND), U2.8 (VSSA), U2.23 (VSS), U2.35 (VSS), U2.47 (VSS), U3.3 (GND), U3.12 (GND), U4.2 (V_{SS}), U5.2 (GND), U5.25 (GND), U6.4 (PGND), U6.9 (GND), U6.11 (PAD), U7.2 (GND), U8.15 (GND), U8.21 (GND), U8.22 (GND), U8.23 (GND), U8.26 (GND), U8.29 (GND), Y1.2 (GND), Y1.4 (GND)
GPS_Reset: R3.1, U2.11 (PA1)
GPS_Rx: U2.12 (PA2), U3.1 (RXD1)
GPS_TX: U2.13 (PA3), U3.2 (TXD1)
I2C SCL: C22.1, J2.03, R18.1, U2.42 (PB6)
I2C SDL: C21.1, J2.04, R15.1, U2.43 (PB7)
ID: ID1.3, ID1.4, R19.2, U2.40 (PB4)
MISO: U2.16 (PA6), U8.17 (MISO)
MOSI: U2.17 (PA7), U8.18 (MOSI)
NRST: C32.2, R2.2, S2.1, S2.2, U2.7 (NRST)
NSS(CS): U2.14 (PA4), U8.19 (NSS)
unnamed: BT1.1 (+), C11.1, Q1.2 (S), U4.3 (V_{BAT})
unnamed: C6.1, C7.1
unnamed: C27.1, J1.1
unnamed: C27.2, L2.1
unnamed: Charger1.2 (D-), Charger1.3 (D+)
unnamed: C3.1, Charger1.1 (VBUS), R7.1, R10.1, U4.4 (V_{DD})
unnamed: F1.2, FL1.1
unnamed: C15.1, L1.1, Q1.1 (D), R12.1, U6.5 (VIN), U6.6 (EN), U6.8 (PS)
unnamed: Q1.3 (G), R10.2
unnamed: R5.2, U2.20 (PB2)
unnamed: R3.2, R4.2, U3.10 (~RESET)
unnamed: R6.1, U4.5 (PROG)
unnamed: U5.3 (D+), U7.6 (I/O1)
unnamed: U5.4 (D-), U7.4 (I/O2)
unnamed: C14.1, C16.1, C17.2, F1.1, U5.7 (REGIN), U5.8 (VBUS), U7.5 (VBUS)
unnamed: R8.2, U5.20 (RXD)
unnamed: R9.2, U5.21 (TXD)
unnamed: C18.1, U5.16 (VPP)
unnamed: R14.1, U5.9 (~RST)
unnamed: L1.2, U6.3 (L)
unnamed: R12.2, R13.1, U6.7 (UVLO)
unnamed: C19.1, U6.1 (VAUX)
unnamed: U7.1 (I/O1), UART1.A6 (D+), UART1.B6 (D+)
unnamed: U7.3 (I/O2), UART1.A7 (D-), UART1.B7 (D-)
unnamed: L2.2, U8.27 (PA_BOOST)
unnamed: C25.2, U8.5 (XTA), Y2.2
unnamed: C26.2, U8.6 (XTB), Y2.1
unnamed: R17.2, UART1.A5 (CC1)
unnamed: R16.2, UART1.B5 (CC2)
OSC_IN: C6.2, R11.1, U2.5 (PD0_OSC_IN), Y1.3
OSC_OUT: C7.2, R11.2, U2.6 (PD1_OSC_OUT), Y1.1
PC_OSC_IN: C31.1, U2.3 (PC14-OSC32_IN), Y3.1
PC_OSC_OUT: C30.1, U2.4 (PC15-OSC32_OUT), Y3.2
RESET: U2.29 (PA8), U8.7 (~RESET)
RX: R9.1, U2.31 (PA10)
SCK: U2.15 (PA5), U8.16 (SCK)
TX: R8.1, U2.30 (PA9)

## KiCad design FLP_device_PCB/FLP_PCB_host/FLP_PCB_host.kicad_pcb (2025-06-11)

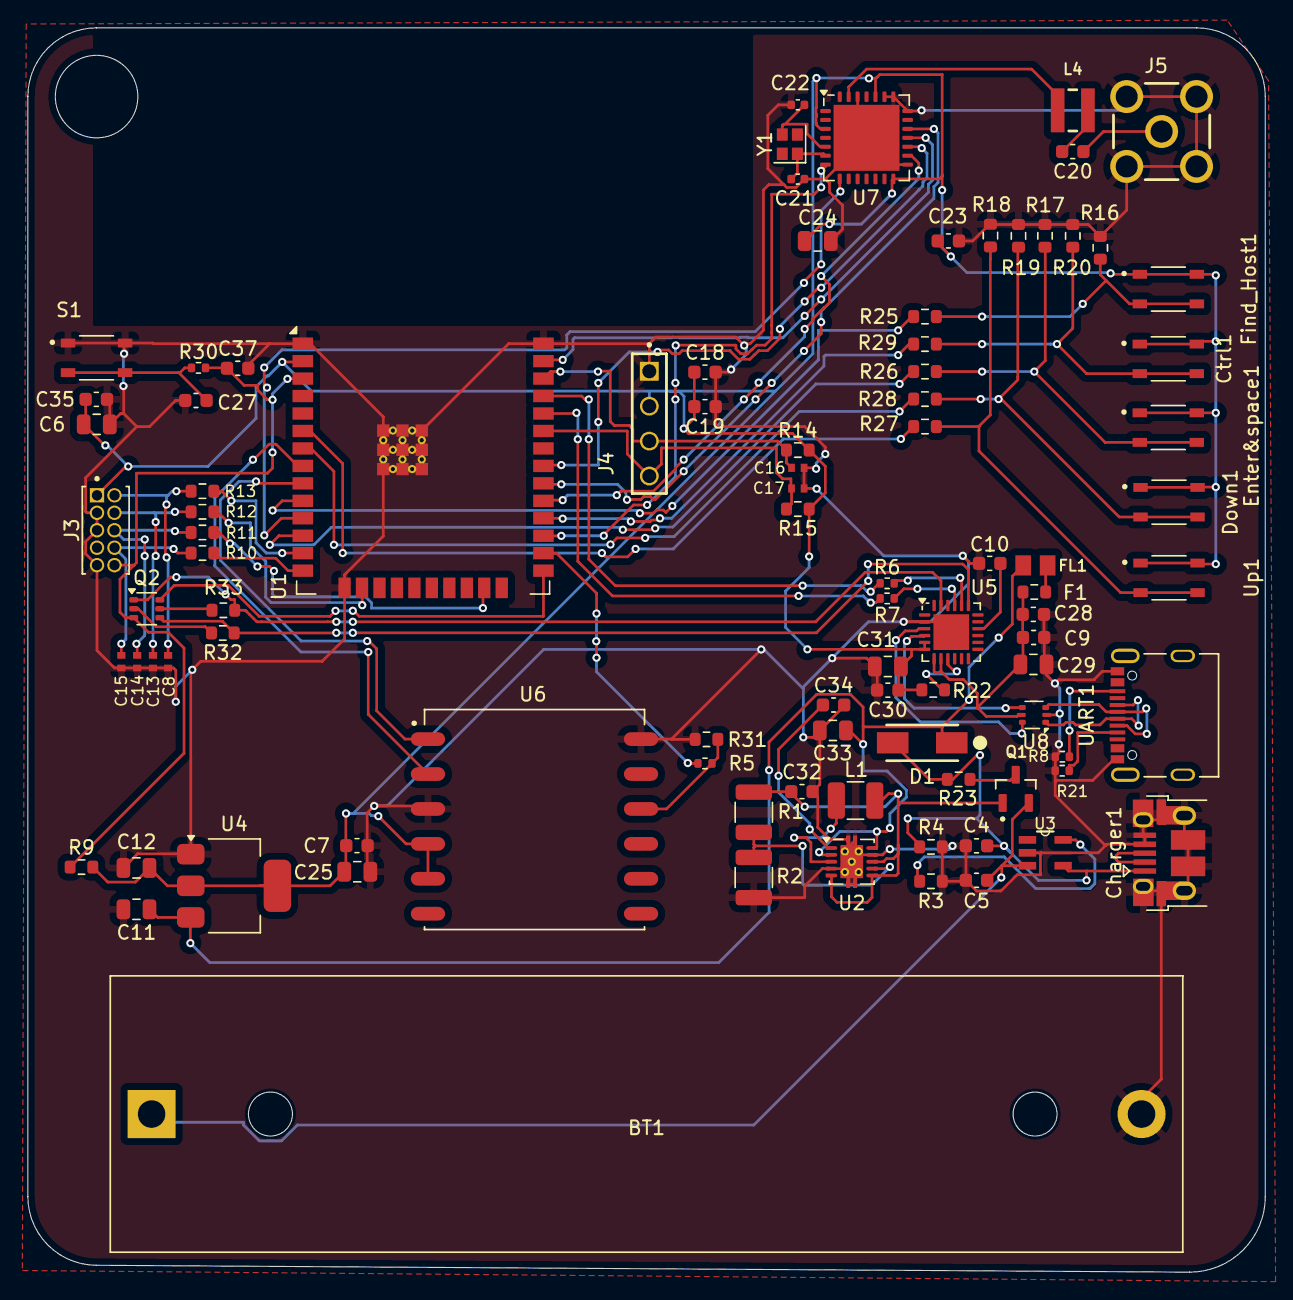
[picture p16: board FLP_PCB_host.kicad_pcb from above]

Board: 2 copper layers, 90.0 x 90.5 mm, 92 parts (0 on the bottom side), 68 nets.

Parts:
BT1: Battery_Cell; BatteryHolder_MPD_BH-18650-PC2
C4, C5, C9, C10, C19, C32: 4.7uF; C_0603_1608Metric
C6, C11, C12, C24, C25, C29, C31, C33: 22uF; C_0805_2012Metric
C7, C34, C35, C37: 1uF; C_0603_1608Metric
C8, C13, C14, C15, C16, C17: PESD0402-140; RESC1005X35N
C18, C23, C27, C28, C30: 0.1uF; C_0603_1608Metric
C20: 27pF; C_0603_1608Metric
C21, C22: 12pF; C_0402_1005Metric
Charger1: 10103594-0001LF; USB_Micro-B_Amphenol_10103594-0001LF_Horizontal
Ctrl1: SKRPABE010; SW_SKRPABE010
D1: MBRA160T3G; DIOM5226X220N
Down1: SKRPABE010; SW_SKRPABE010
Enter&space1: SKRPABE010; SW_SKRPABE010
F1: 0603L100SLYR; R_0603_1608Metric
FL1: BLM21PG221SN1D; BEADC2012X105N
Find_Host1: SKRPABE010; SW_SKRPABE010
J3: GRPB052VWVN-RC; SULLINS_GRPB052VWVN-RC
J4: OLED; SAMTEC_HTSW-104-20-TM-S
J5: SMA-J-P-X-ST-TH1; SAMTEC_SMA-J-P-X-ST-TH1
L1: 2.2uH; L_1210_3225Metric
L4: 744028000056; WE-TPC_2811
Q1: Q_PMOS_DSG; SOT95P237X112-3N
Q2: UMH3N; SOT-363_SC-70-6
R1: 2M; R_1210_3225Metric
R2: 180K; R_1210_3225Metric
R3, R4, R9, R16, R17, R18, R19, R20, R22, R32, R33: 10K; R_0603_1608Metric
R5: 100R; R_0402_1005Metric
R6, R7, R30: 22R; R_0402_1005Metric
R8, R21: 5.1K; R_0402_1005Metric
R10, R11, R12, R13, R25, R26, R27, R28, R29: 100R; R_0603_1608Metric
R14, R15: 2.2K; R_0603_1608Metric
R23, R31: 1K; R_0603_1608Metric
S1: SKRPABE010; SW_SKRPABE010
U1: ESP32-WROOM-32E
U2: TPS61200DRC; Texas_S-PVSON-N10_ThermalVias
U3: MCP73831-2-OT; SOT95P280X145-5N
U4: AMS1117-3.3; SOT-223-3_TabPin2
U5: CP2104; QFN-24-1EP_4x4mm_P0.5mm_EP2.6x2.6mm
U6: L86-M33; XCVR_L86-M33
U7: SX1278; QFN-28-1EP_6x6mm_P0.65mm_EP4.8x4.8mm
U8: USBLC6-2P6; SOT-666
UART1: 12402012E212A; AMPHENOL_12402012E212A
Up1: SKRPABE010; SW_SKRPABE010
Y1: 32MHz; Crystal_SMD_2016-4Pin_2.0x1.6mm

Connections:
3.3V OUT: C6.1, C7.1, C12.1, C18.1, C19.1, C23.1, C24.2, C25.1, C30.1, C31.2, C35.1, Ctrl1.1, Ctrl1.2, Down1.1, Down1.2, Enter&space1.1, Enter&space1.2, Find_Host1.1, Find_Host1.2, J3.1, J4.02, R9.2, R14.2, R15.2, R22.2, U1.2 (VDD), U4.2 (VO), U5.5 (VIO), U5.6 (VDD), U6.4 (VCC), U6.5 (V_BCKP), U7.3 (VBAT_ANA), U7.14 (VBAT_DIG), U7.24 (VBAT_RF), Up1.1, Up1.2
5v OUT: C11.1, C33.1, FL1.2, U2.2 (VOUT), U2.10 (FB), U4.3 (VI)
Ctrl: R29.2, U1.28 (IO17)
DIO0(IRQ): U1.11 (IO26), U7.8 (DIO0)
DTR: Q2.1 (E1), R33.1, U5.23 (~DTR)
Down: R28.2, U1.7 (IO35)
EN: C37.1, J3.10, Q2.3 (C2), R9.1, R30.2, U1.3 (EN)
Enter&space: R26.2, U1.12 (IO27)
Find_Host: R25.2, U1.10 (IO25)
GND: BT1.2 (-), C4.2, C5.2, C6.2, C7.2, C8.2, C9.2, C10.2, C11.2, C12.2, C13.2, C14.2, C15.2, C16.2, C17.2, C18.2, C19.2, C21.1, C22.1, C23.2, C24.1, C25.2, C27.1, C28.1, C29.2, C30.2, C31.1, C32.2, C33.2, C34.2, C35.2, C37.2, Charger1.4 (ID), Charger1.5 (GND), Charger1.6 (Shield), J3.3, J3.5, J3.9, J4.01, J5.2, J5.3, J5.4, J5.5, R2.2, R3.2, R4.2, R8.1, R16.2, R17.2, R18.2, R19.2, R20.2, R21.1, R31.1, S1.1, S1.2, U1.1 (GND), U1.15 (GND), U1.38 (GND), U1.39 (GND), U2.4 (PGND), U2.9 (GND), U2.11 (PAD), U3.2 (V_{SS}), U4.1 (GND), U5.2 (GND), U5.25 (GND), U6.3 (GND), U6.12 (GND), U7.15 (GND), U7.21 (GND), U7.22 (GND), U7.23 (GND), U7.26 (GND), U7.29 (GND), U8.2 (GND)
GPS_Reset: R5.1, U1.26 (IO4)
GPS_Rx: U1.9 (IO33), U6.1 (RXD1)
GPS_TX: U1.8 (IO32), U6.2 (TXD1)
I2C SCL: C16.1, J4.03, R14.1, U1.36 (IO22)
I2C SDL: C17.1, J4.04, R15.1, U1.33 (IO21)
IO0: Q2.6 (C1), U1.25 (IO0)
MISO: U1.31 (IO19), U7.17 (MISO)
MOSI: U1.37 (IO23), U7.18 (MOSI)
MTCK: R12.1, U1.16 (IO13)
MTDI: R10.1, U1.14 (IO12)
MTDO: R11.1, U1.23 (IO15)
MTMS: R13.1, U1.13 (IO14)
NSS(CS): U1.30 (IO18), U7.19 (NSS)
unnamed: BT1.1 (+), C5.1, Q1.2 (S), U3.3 (V_{BAT})
unnamed: C8.1, J3.2, R13.2
unnamed: C13.1, J3.4, R12.2
unnamed: C14.1, J3.6, R11.2
unnamed: C15.1, J3.8, R10.2
unnamed: C20.1, J5.1
unnamed: C20.2, L4.1
unnamed: C27.2, R30.1, S1.3, S1.4
unnamed: Charger1.2 (D-), Charger1.3 (D+)
unnamed: C4.1, Charger1.1 (VBUS), R4.1, R23.1, U3.4 (V_{DD})
unnamed: Ctrl1.3, Ctrl1.4, R20.1, R29.1
unnamed: Down1.3, Down1.4, R19.1, R28.1
unnamed: Enter&space1.3, Enter&space1.4, R17.1, R26.1
unnamed: F1.2, FL1.1
unnamed: Find_Host1.3, Find_Host1.4, R16.1, R25.1
unnamed: C32.1, L1.1, Q1.1 (D), R1.1, U2.5 (VIN), U2.6 (EN), U2.8 (PS)
unnamed: Q1.3 (G), R23.2
unnamed: Q2.2 (B1), R32.2
unnamed: Q2.5 (B2), R33.2
unnamed: R18.1, R27.1, Up1.3, Up1.4
unnamed: L1.2, U2.3 (L)
unnamed: R1.2, R2.1, U2.7 (UVLO)
unnamed: C34.1, U2.1 (VAUX)
unnamed: R3.1, U3.5 (PROG)
unnamed: U5.3 (D+), U8.6 (I/O1)
unnamed: U5.4 (D-), U8.4 (I/O2)
unnamed: C9.1, C28.2, C29.1, F1.1, U5.7 (REGIN), U5.8 (VBUS), U8.5 (VBUS)
unnamed: R6.2, U5.20 (RXD)
unnamed: R7.2, U5.21 (TXD)
unnamed: C10.1, U5.16 (VPP)
unnamed: R22.1, U5.9 (~RST)
unnamed: R5.2, R31.2, U6.10 (~RESET)
unnamed: L4.2, U7.27 (PA_BOOST)
unnamed: C22.2, U7.5 (XTA), Y1.3
unnamed: C21.2, U7.6 (XTB), Y1.1
unnamed: U8.1 (I/O1), UART1.A6 (D+), UART1.B6 (D+)
unnamed: U8.3 (I/O2), UART1.A7 (D-), UART1.B7 (D-)
unnamed: R21.2, UART1.A5 (CC1)
unnamed: R8.2, UART1.B5 (CC2)
RESET: U1.27 (IO16), U7.7 (~RESET)
RTS: Q2.4 (E2), R32.1, U5.19 (~RTS)
RX: R7.1, U1.34 (RXD0/IO3)
SCK: U1.29 (IO5), U7.16 (SCK)
TX: R6.1, U1.35 (TXD0/IO1)
Up: R27.2, U1.6 (IO34)

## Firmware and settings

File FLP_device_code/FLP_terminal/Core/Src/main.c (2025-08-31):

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
/* Includes ------------------------------------------------------------------*/
#include "main.h"

/* USER CODE BEGIN Includes */
#include "stdio.h"
#include "stdlib.h"
#include "string.h"
#include "stdint.h"
/* USER CODE END Includes */

/* USER CODE BEGIN PTD */
typedef struct GpsData{
	float latitude;
	float longitude;
}GpsData;
/* USER CODE END PTD */

/* USER CODE BEGIN PD */
#define TERMINAL_ID_INT 2041235739
#define TERMINAL_ID_CHAR "2041235739"
#define LORA_MAX_PACKET_SIZE 255
/* USER CODE END PD */

SPI_HandleTypeDef hspi1;

UART_HandleTypeDef huart2;

/* USER CODE BEGIN PV */
uint8_t gps_rx_buffer[1];
char gps_sentence[128];
uint8_t gps_index = 0;
GpsData SaveGpsData;
int host_id;
static int danger = 0;
/* USER CODE END PV */

void SystemClock_Config(void);
static void MX_GPIO_Init(void);
static void MX_SPI1_Init(void);
static void MX_USART2_UART_Init(void);
/* USER CODE BEGIN PFP */
void lora_write_register(uint8_t reg, uint8_t value) {
    uint8_t tx_buf[2] = { (reg | 0x80), value };

    HAL_GPIO_WritePin(GPIOA, SX1278_NSS_Pin, GPIO_PIN_RESET);
    HAL_SPI_Transmit(&hspi1, tx_buf, 2, HAL_MAX_DELAY);
    HAL_GPIO_WritePin(GPIOA, SX1278_NSS_Pin, GPIO_PIN_SET);
}

uint8_t lora_read_register(uint8_t reg) {
    uint8_t tx_buf[2] = { (reg & 0x7F), 0x00 };
    uint8_t rx_buf[2] = { 0 };

    HAL_GPIO_WritePin(GPIOA, SX1278_NSS_Pin, GPIO_PIN_RESET);
    HAL_SPI_TransmitReceive(&hspi1, tx_buf, rx_buf, 2, HAL_MAX_DELAY);
    HAL_GPIO_WritePin(GPIOA, SX1278_NSS_Pin, GPIO_PIN_SET);

    return rx_buf[1];
}

void lora_init(void) {
    HAL_GPIO_WritePin(GPIOB, SX1278_RESET_Pin, GPIO_PIN_RESET);
    HAL_Delay(10);
    HAL_GPIO_WritePin(GPIOB, SX1278_RESET_Pin, GPIO_PIN_SET);
    HAL_Delay(10);

    lora_write_register(0x01, 0x81);

    uint64_t frf = ((uint64_t)433000000 << 19) / 32000000;
    lora_write_register(0x06, (frf >> 16) & 0xFF);
    lora_write_register(0x07, (frf >> 8) & 0xFF);
    lora_write_register(0x08, (frf >> 0) & 0xFF);

    lora_write_register(0x1D, 0x72);
    lora_write_register(0x1E, 0xC4);
    lora_write_register(0x22, LORA_MAX_PACKET_SIZE);


    lora_write_register(0x12, 0xFF);
}

double convert_to_decimal_degrees(const char* nmea_coord, char direction) {
    double raw = atof(nmea_coord);
    int degrees = (int)(raw / 100);
    double minutes = raw - (degrees * 100);
    double decimal_degrees = degrees + (minutes / 60.0);

    if (direction == 'S' || direction == 'W') {
        decimal_degrees *= -1.0;
    }

    return decimal_degrees;
}

void parse_gps_sentence(char* gps_input) {
    if (!(strstr(gps_input, "$GPGGA") || strstr(gps_input, "$GPRMC"))) {
        return;
    }

    char *token;
    int field_index = 0;
    char lat[16] = {0}, lon[16] = {0};
    char lat_dir = 0, lon_dir = 0;

    token = strtok(gps_input, ",");

    while (token != NULL) {
        field_index++;

        if (field_index == 3) {
            strncpy(lat, token, sizeof(lat) - 1);
        }
        else if (field_index == 4) {
            lat_dir = token[0];
        }
        else if (field_index == 5) {
            strncpy(lon, token, sizeof(lon) - 1);
        }
        else if (field_index == 6) {
            lon_dir = token[0];
        }

        token = strtok(NULL, ",");
    }

    if (strlen(lat) > 0 && strlen(lon) > 0) {
        double conv_lat = convert_to_decimal_degrees(lat, lat_dir);
        double conv_lon = convert_to_decimal_degrees(lon, lon_dir);

        if (conv_lat >= -90 && conv_lat <= 90 && conv_lon >= -180 && conv_lon <= 180) {
            SaveGpsData.latitude = conv_lat;
            SaveGpsData.longitude = conv_lon;
        }
    }
}

void lora_send_packet(const char* data) {
    size_t len = strlen(data);
    if (len > 255) len = 255;

    lora_write_register(0x01, 0x81);
    lora_write_register(0x0E, 0x00);
    lora_write_register(0x0D, 0x00);

    for (size_t i = 0; i < len; i++) {
        lora_write_register(0x00, data[i]);
    }

    lora_write_register(0x22, len);
    lora_write_register(0x01, 0x83);
    while ((lora_read_register(0x12) & 0x08) == 0) {
        HAL_Delay(10);
    }
    lora_write_register(0x12, 0xFF);
}

int lora_receive_packet(char *buf, size_t max_len) {
    if (buf == NULL || max_len == 0) return 0;

    int len = 0;
    uint8_t irq_flags = lora_read_register(0x12);

    if (irq_flags & 0x40) {
        if (irq_flags & 0x20) {
            lora_write_register(0x12, 0xFF);
            return 0;
        }

        len = lora_read_register(0x13);

        if (len > max_len - 1){
        	len = max_len - 1;
        }

        uint8_t fifo_addr = lora_read_register(0x10);
        lora_write_register(0x0D, fifo_addr);

        for (int i = 0; i < len; i++) {
            buf[i] = lora_read_register(0x00);
        }
        buf[len] = '\0';

        int rssi = lora_read_register(0x1A);
        printf("LoRa RX %d bytes (RSSI=%d): %s\r\n", len, rssi, buf);
    }
    lora_write_register(0x12, 0xFF);
    return len;
}

void buzzer_beep_once() {
    HAL_GPIO_WritePin(buzzer_GPIO_Port, buzzer_Pin, GPIO_PIN_SET);
    HAL_Delay(10000);
    HAL_GPIO_WritePin(buzzer_GPIO_Port, buzzer_Pin, GPIO_PIN_RESET);
}

void buzzer_alarm_repeat() {
    for (int i = 0; i < 3; i++) {
        HAL_GPIO_WritePin(buzzer_GPIO_Port, buzzer_Pin, GPIO_PIN_SET);
        HAL_Delay(2000);
        HAL_GPIO_WritePin(buzzer_GPIO_Port, buzzer_Pin, GPIO_PIN_RESET);
        HAL_Delay(2000);
    }
}

void buzzer_off() {
    HAL_GPIO_WritePin(buzzer_GPIO_Port, buzzer_Pin, GPIO_PIN_RESET);
}

void lora_receive_handler(void) {
    char buf[256] = {0};
    int packet_len = lora_receive_packet(buf,255);

    if (packet_len > 0) {
        buf[packet_len] = '\0';
        printf("LoRa Received: %s\n", buf);
        if (strstr(buf, "getgps") != NULL) {
        	char * token;
        	token = strtok(buf,",");
        	if(strstr(token,TERMINAL_ID_CHAR)){
        		token = strtok(buf,NULL);
        		host_id = atoi(token);

        		token = strtok(buf,NULL);
        		danger = atoi(token);

        		switch (danger) {
					case 0:
						buzzer_off();
						break;
					case 1:
						buzzer_beep_once();
						break;
					case 2:
					case 3:
						buzzer_alarm_repeat();
						break;
					default:
						buzzer_off();
						break;
				}

        		char response[64];
				snprintf(response, sizeof(response), "%u,%.4f,%.4f %u", TERMINAL_ID_INT, SaveGpsData.latitude, SaveGpsData.longitude, host_id);

				lora_send_packet(response);
				printf("LoRa Sent: %s\n", response);
        	}
        }
    }
}


/* USER CODE END PFP */

/**
  * @brief  The application entry point.
  * @retval int
  */
int main(void)
{

  /* MCU Configuration--------------------------------------------------------*/

  /* Reset of all peripherals, Initializes the Flash interface and the Systick. */
  HAL_Init();

  /* Configure the system clock */
  SystemClock_Config();

  /* USER CODE BEGIN SysInit */
  lora_init();
  /* USER CODE END SysInit */

  /* Initialize all configured peripherals */
  MX_GPIO_Init();
  MX_SPI1_Init();
  MX_USART2_UART_Init();
  /* USER CODE BEGIN 2 */
  HAL_UART_Receive_IT(&huart2, gps_rx_buffer, 1);
  /* USER CODE END 2 */

  /* Infinite loop */
  /* USER CODE BEGIN WHILE */
  while (1)
  {
    /* USER CODE END WHILE */
	  if(HAL_GPIO_ReadPin(GPIOE, find_host_Pin)){
		  lora_send_packet();

	  }

    /* USER CODE BEGIN 3 */
  }
  /* USER CODE END 3 */
}

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
/* USER CODE BEGIN 4 */
void HAL_UART_RxCpltCallback(UART_HandleTypeDef *huart)
{
    if (huart->Instance == USART2) {
        if (gps_rx_buffer[0] == '\n') {
            gps_sentence[gps_index] = '\0';
            gps_index = 0;
            parse_gps_sentence(gps_sentence);
        } else {
            gps_sentence[gps_index++] = gps_rx_buffer[0];
            if (gps_index >= 127) gps_index = 0;
        }
        HAL_UART_Receive_IT(&huart2, gps_rx_buffer, 1);
    }
}

void HAL_GPIO_EXTI_Callback(uint16_t GPIO_Pin)
{
    if (GPIO_Pin == DIO0_Pin) {
    	lora_receive_handler();
    }
}
/* USER CODE END 4 */
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


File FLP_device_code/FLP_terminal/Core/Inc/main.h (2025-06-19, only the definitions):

#define GPS_Rx_Pin GPIO_PIN_2
#define GPS_Rx_GPIO_Port GPIOA
#define GPS_Tx_Pin GPIO_PIN_3
#define GPS_Tx_GPIO_Port GPIOA
#define SX1278_NSS_Pin GPIO_PIN_4
#define SX1278_NSS_GPIO_Port GPIOA
#define SX1278_SCK_Pin GPIO_PIN_5
#define SX1278_SCK_GPIO_Port GPIOA
#define SX1278_MISO_Pin GPIO_PIN_6
#define SX1278_MISO_GPIO_Port GPIOA
#define SX1278_MOSI_Pin GPIO_PIN_7
#define SX1278_MOSI_GPIO_Port GPIOA
#define DIO0_Pin GPIO_PIN_1
#define DIO0_GPIO_Port GPIOB
#define buzzer_Pin GPIO_PIN_11
#define buzzer_GPIO_Port GPIOA
#define find_host_Pin GPIO_PIN_3
#define find_host_GPIO_Port GPIOB
#define ID_Pin GPIO_PIN_4
#define ID_GPIO_Port GPIOB
#define SX1278_RESET_Pin GPIO_PIN_8
#define SX1278_RESET_GPIO_Port GPIOB

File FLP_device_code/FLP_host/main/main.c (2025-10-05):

#include "freertos/FreeRTOS.h"
#include "freertos/task.h"
#include "esp_log.h"
#include "driver/gpio.h"
#include "cJSON.h"
#include <string.h>
#include <stdlib.h>

#include "common/common_types.h"
#include "nvs_storage.h"
#include "wifi_manager.h"
#include "lora_driver.h"
#include "gps_reader.h"
#include "device_manager.h"
#include "web_server.h"
#include "websocket_client.h"

static const char* TAG = "APP_MAIN";
static const int my_id_int = 1726384219;
static const char *my_id_char = "1726384219";

#define CTRL      GPIO_NUM_17
#define FIND_HOST GPIO_NUM_25

static bool split_lora_response(char* input, TerminalDevice* info) {
    char* token;
    token = strtok(input, ",");
    if (token == NULL || info->Code != atoi(token)) return false;
    
    token = strtok(NULL, ",");
    if (token == NULL) return false;
    info->Latit = atof(token);
    
    token = strtok(NULL, ",");
    if (token == NULL) return false;
    info->Longit = atof(token);
    
    token = strtok(NULL, ",");
    if (token == NULL || my_id_int != atoi(token)) return false;

    return true;
}

static char* make_json_payload(void) {
    cJSON *root = cJSON_CreateObject();
    cJSON_AddStringToObject(root, "hostId", my_id_char);

    cJSON *members_array = cJSON_CreateArray();
    size_t count = device_manager_get_device_count();

    for (int i = 0; i < count; i++) {
        TerminalDevice dev;
        if (device_manager_get_device_by_index(i, &dev)) {
            cJSON *member = cJSON_CreateObject();
            cJSON_AddNumberToObject(member, "memberId", dev.Code);
            cJSON_AddNumberToObject(member, "lat", dev.Latit);
            cJSON_AddNumberToObject(member, "lon", dev.Longit);
            cJSON_AddItemToArray(members_array, member);
        }
    }
    cJSON_AddItemToObject(root, "members", members_array);

    char *json_str = cJSON_PrintUnformatted(root);
    cJSON_Delete(root);
    return json_str;
}

void lora_host_task(void *pvParameters) {
    const TickType_t timeout_ticks = pdMS_TO_TICKS(5000);

    while (1) {
        size_t device_count = device_manager_get_device_count();
        ESP_LOGI(TAG, "LoRa 태스크 시작, %d개의 장치를 순회합니다.", device_count);

        for (int i = 0; i < device_count; i++) {
            TerminalDevice current_device;
            if (!device_manager_get_device_by_index(i, &current_device)) continue;
            
            char gps_request_msg[64];
            snprintf(gps_request_msg, sizeof(gps_request_msg), "%u,%u,%u,getgps", current_device.Code, my_id_int, current_device.Danger);
            lora_send_packet(gps_request_msg);
            ESP_LOGI(TAG, "Sent to %d: %s", current_device.Code, gps_request_msg);

            TickType_t start_time = xTaskGetTickCount();
            bool received = false;
            while ((xTaskGetTickCount() - start_time) < timeout_ticks) {
                char buf[LORA_MAX_PACKET_SIZE] = {0};
                if (lora_receive_packet(buf) > 0) {
                    if (strstr(buf, my_id_char) != NULL) {
                        if (split_lora_response(buf, &current_device)) {
                            device_manager_update_device_info(current_device.Code, current_device.Latit, current_device.Longit, current_device.Danger);
                            ESP_LOGI(TAG, "Received from %d: Lat=%f, Lon=%f", current_device.Code, current_device.Latit, current_device.Longit);
                            received = true;
                            break;
                        }
                    }
                }
                vTaskDelay(pdMS_TO_TICKS(10));
            }

            if (!received) {
                ESP_LOGW(TAG, "Device %d로부터 응답 시간 초과", current_device.Code);
            }
        }

        if (websocket_client_is_connected() && device_count > 0) {
            char* json_payload = make_json_payload();
            if (json_payload) {
                websocket_client_send_text(json_payload);
                free(json_payload);
            }
        }
        
        vTaskDelay(pdMS_TO_TICKS(1000));
    }
}


void app_main(void) {
    ESP_LOGI(TAG, "===== FLP Host 시스템 시작 =====");

    ESP_ERROR_CHECK(nvs_storage_init());
    ESP_ERROR_CHECK(wifi_manager_init_apsta());
    
    device_manager_init();
    ESP_ERROR_CHECK(lora_init());
    ESP_ERROR_CHECK(gps_reader_init());
    ESP_ERROR_CHECK(web_server_start());
    ESP_ERROR_CHECK(websocket_client_start());

    xTaskCreate(lora_host_task, "lora_host_task", 4096, NULL, 5, NULL);
    
    gpio_set_direction(CTRL, GPIO_MODE_INPUT);
    gpio_set_pull_mode(CTRL, GPIO_PULLDOWN_ONLY);
    gpio_set_direction(FIND_HOST, GPIO_MODE_INPUT);
    gpio_set_pull_mode(FIND_HOST, GPIO_PULLDOWN_ONLY);

    ESP_LOGI(TAG, "초기화 완료. 메인 루프 진입.");
    while (1) {
		if (gpio_get_level(CTRL) == 1 && gpio_get_level(FIND_HOST) == 1) {
			ESP_LOGI(TAG, "장치 등록 모드 진입 (10초)");
			TickType_t start_time = xTaskGetTickCount();
			while ((xTaskGetTickCount() - start_time) < pdMS_TO_TICKS(10000)) {
				char buf[LORA_MAX_PACKET_SIZE] = {0};
				if (lora_receive_packet(buf) > 0 && strstr(buf, "FINDHOST") != NULL) {
					int add_id = 0;
					char *token = strtok(buf, ",");
                    if (token) token = strtok(NULL, ",");
					if (token) add_id = atoi(token);

					if (add_id > 0) {
						ESP_LOGI(TAG, "장치 등록 요청 수신 ID: %d", add_id);
						if (device_manager_add_device(add_id)) {
							ESP_LOGI(TAG, "장치 %d 추가 성공", add_id);
						} else {
							ESP_LOGW(TAG, "장치 %d 추가 실패", add_id);
						}
					}
					break; 
				}
				vTaskDelay(pdMS_TO_TICKS(10));
			}
			ESP_LOGI(TAG, "장치 등록 모드 종료.");
		}
		vTaskDelay(pdMS_TO_TICKS(100));
	}
}

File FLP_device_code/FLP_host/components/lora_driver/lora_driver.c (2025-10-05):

/*
 * lora_driver.c
 *
 *  Created on: 2025. 10. 5.
 *      Author: user
 */

#include "lora_driver.h"
#include "freertos/FreeRTOS.h"
#include "freertos/task.h"
#include <string.h>

static spi_device_handle_t lora_spi;

static void lora_write_register(uint8_t reg, uint8_t val) {
    spi_transaction_t t = {
        .length = 8 * 2,
        .tx_buffer = (uint8_t[]){ reg | 0x80, val }
    };
    spi_device_transmit(lora_spi, &t);
}

static uint8_t lora_read_register(uint8_t reg) {
    uint8_t out;
    uint8_t tx[2] = { reg & 0x7F, 0x00 };
    uint8_t rx[2];
    spi_transaction_t t = {
        .length = 8 * 2,
        .tx_buffer = tx,
        .rx_buffer = rx
    };
    spi_device_transmit(lora_spi, &t);
    out = rx[1];
    return out;
}

esp_err_t lora_init(void) {
    spi_bus_config_t bus_config = {
        .miso_io_num = PIN_NUM_MISO,
        .mosi_io_num = PIN_NUM_MOSI,
        .sclk_io_num = PIN_NUM_CLK,
        .quadwp_io_num = -1,
        .quadhd_io_num = -1
    };

    spi_device_interface_config_t device_config = {
        .clock_speed_hz = 1 * 1000 * 1000,
        .mode = 0,
        .spics_io_num = PIN_NUM_CS,
        .queue_size = 7
    };

    esp_err_t ret;
    ret = spi_bus_initialize(LORA_SPI_HOST, &bus_config, SPI_DMA_CH_AUTO);
    if (ret != ESP_OK) return ret;
    ret = spi_bus_add_device(LORA_SPI_HOST, &device_config, &lora_spi);
    if (ret != ESP_OK) return ret;

    gpio_set_direction(PIN_NUM_RST, GPIO_MODE_OUTPUT);
    gpio_set_level(PIN_NUM_RST, 0);
    vTaskDelay(pdMS_TO_TICKS(10));
    gpio_set_level(PIN_NUM_RST, 1);
    vTaskDelay(pdMS_TO_TICKS(10));

    lora_write_register(0x01, 0x80);
    lora_write_register(0x01, 0x81);

    uint64_t frf = ((uint64_t)LORA_FREQUENCY << 19) / 32000000;
    lora_write_register(0x06, (frf >> 16) & 0xFF);
    lora_write_register(0x07, (frf >> 8) & 0xFF);
    lora_write_register(0x08, (frf >> 0) & 0xFF);

    lora_write_register(0x1D, 0x72);
    lora_write_register(0x1E, 0xA4);

    lora_write_register(0x20, 0x00);
    lora_write_register(0x21, 0x08);

    lora_write_register(0x1F, 0x00);

    return ESP_OK;
}

void lora_send_packet(const char* data) {
    size_t len = strlen(data);

    lora_write_register(0x01, 0x81);

    lora_write_register(0x0E, 0x00);
    lora_write_register(0x0D, 0x00);

    for (int i = 0; i < len; i++) {
        lora_write_register(0x00, data[i]);
    }

    lora_write_register(0x22, len);
    lora_write_register(0x01, 0x83);

    while ((lora_read_register(0x12) & 0x08) == 0) {
        vTaskDelay(pdMS_TO_TICKS(10));
    }

    lora_write_register(0x12, 0xFF);
}

int lora_receive_packet(char *buf) {
    int len = 0;
    uint8_t irq_flags = lora_read_register(0x12);

    if (irq_flags & 0x40) { // RxDone flag
        len = lora_read_register(0x13);

        if (len > LORA_MAX_PACKET_SIZE) {
            len = LORA_MAX_PACKET_SIZE;
        }

        uint8_t fifo_addr = lora_read_register(0x10);
        lora_write_register(0x0D, fifo_addr);

        for (int i = 0; i < len; i++) {
            buf[i] = lora_read_register(0x00);
        }
        buf[len] = '\0';

        lora_write_register(0x12, 0xFF);
    }
    return len;
}

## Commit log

2025-03-17 PCB update
    [mistance_PCB.kicad_pcb, mistance_PCB.kicad_sch]
2025-03-30 PCB first chack
    [mistance_PCB.kicad_pcb]
2025-03-30 PCB first chack end
    [mistance_PCB.kicad_pcb, mistance_PCB.kicad_sch]
2025-03-30 PCB add GND plain
    [mistance_PCB.kicad_pcb]
2025-03-30 PCB last add GND plain
    [mistance_PCB.kicad_pcb]
2025-04-04 SCH update, PCB reset
    [mistance_PCB.kicad_sch, mistance_PCB_host.kicad_pcb, mistance_PCB_host.kicad_sch]
2025-04-05 SCH finish PCB writing
    [mistance_PCB_host.kicad_pcb, mistance_PCB_host.kicad_sch]
2025-04-06 PCB writing
    [mistance_PCB_host.kicad_pcb, mistance_PCB_host.kicad_sch]
2025-04-08 host PCB and SCH finish
    [mistance_PCB_host.kicad_pcb]
2025-04-13 terminal SCH
    [mistance_PCB_host.csv, mistance_PCB_host.kicad_sch, mistance_PCB_terminal.kicad_pcb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]
2025-04-15 modify terminal SCH
    [mistance_PCB_terminal.kicad_sch]
2025-04-18 host PCB and SCH bug fix
    [mistance_PCB_host.kicad_pcb, mistance_PCB_host.kicad_sch]
2025-04-23 host code
    [mistance_PCB_host.kicad_pcb, mistance_PCB_host.kicad_sch]
2025-04-28 host code modify & host PCB and SCH modify
    [mistance_PCB_host.kicad_pcb, mistance_PCB_host.kicad_sch]
2025-05-05 PCB and code modify
2025-05-14 name fix and grb file add
    [FLP_PCB_host-B_Cu.gbr, FLP_PCB_host-B_Mask.gbr, FLP_PCB_host-B_Paste.gbr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]
2025-05-16 dir name change, host PCB finish
    [FLP_PCB_host-B_Cu.gbr, FLP_PCB_host-B_Mask.gbr, FLP_PCB_host-B_Paste.gbr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]
2025-06-03 PCB finish
    [FLP_PCB_host.kicad_pcb, FLP_PCB_terminal.kicad_pcb]
2025-06-11 code adding
    [FLP_PCB_host-B_Cu.gbr, FLP_PCB_host-B_Mask.gbr, FLP_PCB_host-B_Paste.gbr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]
2025-06-16 code add
    [case.blend]
2025-06-19 PCB build up -> nomal modify
    [FLP_PCB_terminal-B_Cu.gbr, FLP_PCB_terminal-B_Mask.gbr, FLP_PCB_terminal-B_Paste.gbr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]
2025-06-19 WSS fix and Post fix and Optimization
    [main.c]
2025-06-21 rename folder name and terminal define function
    [FLP_PCB_host-B_Cu.gbr, FLP_PCB_host-B_Mask.gbr, FLP_PCB_host-B_Paste.gbr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]
2025-06-23 device_code Refactoring
2025-07-07 device_code fix and device_PCB fix
    [FLP_PCB_terminal.kicad_pcb, FLP_PCB_terminal.kicad_sch]
2025-08-09 code fix
    [untitled.blend]
2025-09-13 new PCB adding
    [FLP_PCB_set.kicad_pcb, FLP_PCB_set.kicad_sch, FLP_host.kicad_sch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]
2025-09-18 FLP_set add
    [5v_to_3.3V.kicad_sch, BOOT_Mode.kicad_sch, Bat.kicad_sch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]
2025-09-29 PCB fixing end adding description pdf
    [5v_to_3.3V.kicad_sch, BOOT_Mode.kicad_sch, Bat.kicad_sch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]
2025-10-07 PCB pdf add
    [Bat.kicad_sch, FLP_PCB_set.kicad_pcb, FLP_PCB_set.kicad_sch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]

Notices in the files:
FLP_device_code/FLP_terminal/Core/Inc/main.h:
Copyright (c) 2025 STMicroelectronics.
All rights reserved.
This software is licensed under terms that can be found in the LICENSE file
